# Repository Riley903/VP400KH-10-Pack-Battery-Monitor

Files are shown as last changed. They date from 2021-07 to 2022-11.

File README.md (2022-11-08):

# Battery Back-up System

This project is the entriety of the NiCd battery back-up system used in my parents' house for emergency power in the event of a power failure.

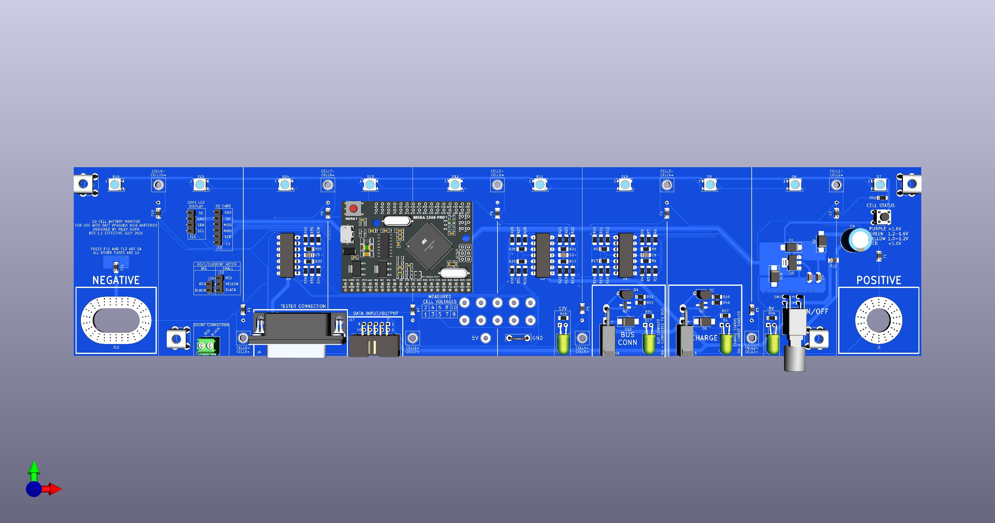
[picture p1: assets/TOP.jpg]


## Original Goal

The original goal of this project was to provide power to a water pump in the event of a power failure to provide water pressure to the house.

Recycling old heavy NiCd aircraft batteries in packs of 10 cells to provide 12V would be the electrical storage since it was free and would not need to be portable.

Several of these packs, originally 4 was deemed sufficient, would be used to power a 12V water pump from the recreational boating industry which provided the necessary 50psi at a reasonable flow rate. 

In addition to this battery storage solution, we planned to designa and build a small test unit that could calculate each cell's capacity such that we could grade them and organize them in packs of similar cells. Having 100s of cells, this is a must.

## Changes to the Original Goal

We were surprised by how effective the system was working as is with 4 packs and the pump, thus we decided to introduce 4 more packs and run an inverter to the house's main panel where it could be distributed through breakers to specific areas of the house. This would be useful for powering the lights and small appliances such as LED TVs, phone chargers, computers, and possibly the fridges and freezers.

## Some Future Plans

- Adding the 4 additional packs is still in the works.
- Water level metering to the storage tank outside.
- Silent charger for the packs.
- Upgrade the packs to the ESP32 dev board as the main controller.
- Once the ESP32's are installed, could implement a locally hosted website to view the packs and cells.
- Battery pack controllable disconnects and connects. (Look into high power transistors/thyristors capable of switching 100s of Amperes).

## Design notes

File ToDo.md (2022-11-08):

# To Do List

- Change "Charging Circuit" into a schematic of the entire system with room for additions to the project.
- Rename repository to "Battery Back-up System" since we are adding (to name a few):
    - Other cell sizes.
    - The analyzer.
    - 3D printed parts.

Check todoist for more.

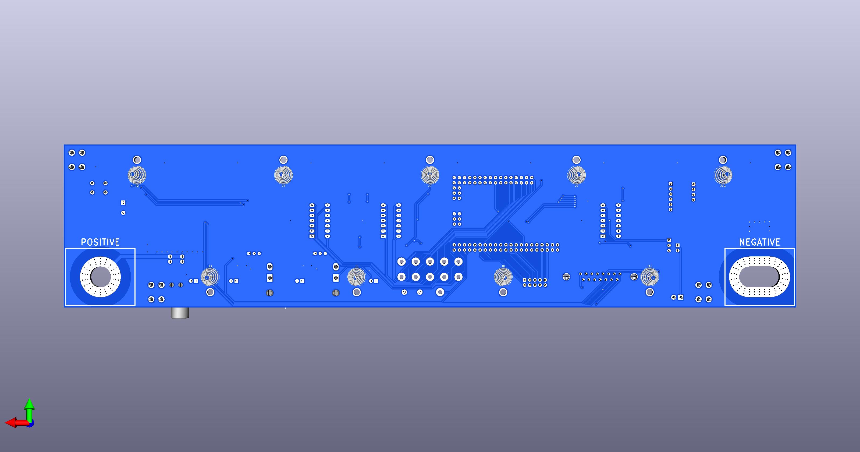
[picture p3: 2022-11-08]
NiCd Battery Shield - VP400KH/NiCd Battery Shield - VP400KH-REV 1.1/BOTTOM.jpg

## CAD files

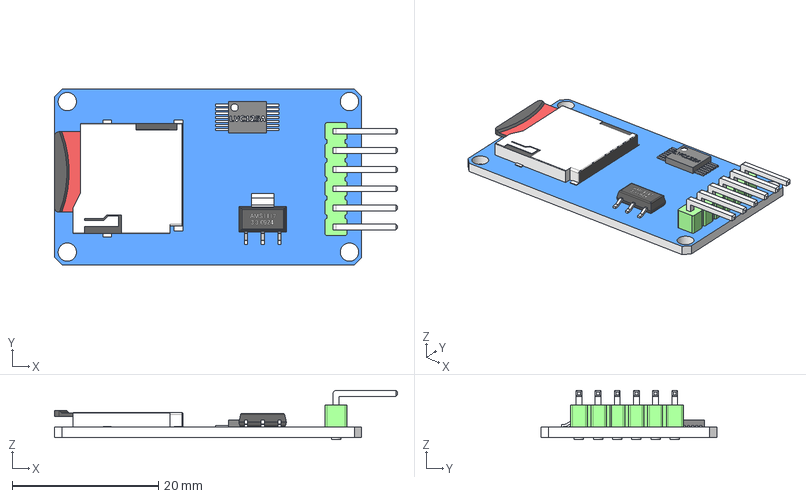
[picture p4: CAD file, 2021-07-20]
NiCd Battery Shield - VP400KH/NiCd Battery Shield - VP400KH-REV 1.1/3D Models/MicroSD Reader Assembly.stp
46.9 x 24.0 x 6.70 mm
sdreader
AMS1117
card sd

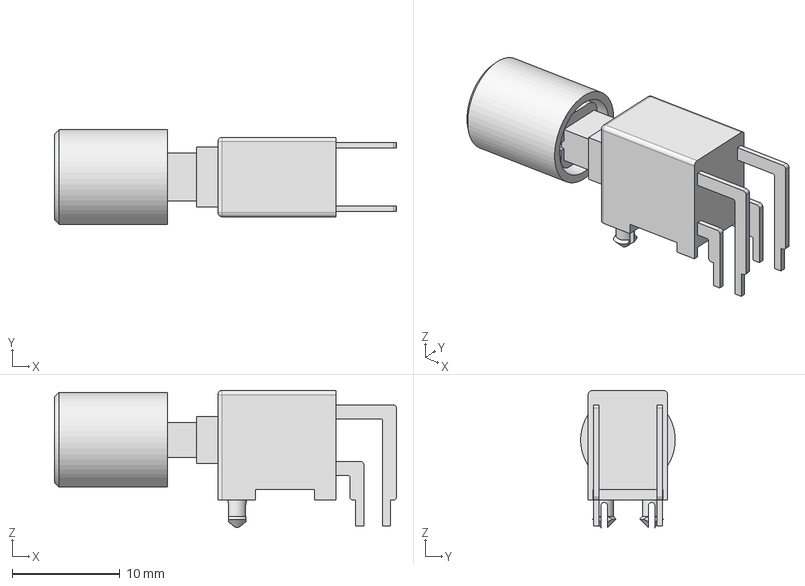
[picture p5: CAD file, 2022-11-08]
NiCd Battery Shield - VP400KH/Charging Dummy Board/3D Models/PB400xxQR1BLK.stp
31.8 x 8.79 x 12.8 mm

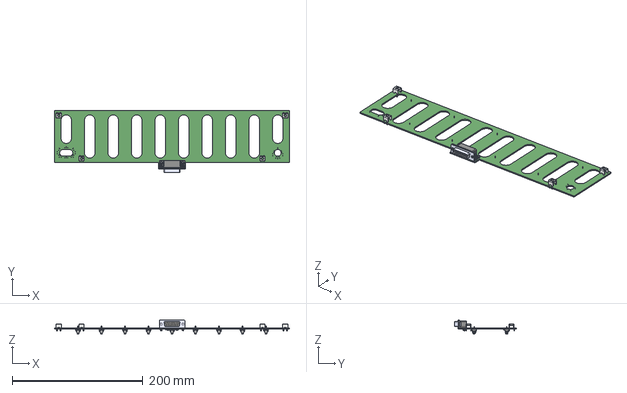
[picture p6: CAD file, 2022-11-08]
NiCd Battery Shield - VP400KH/Charging Dummy Board/NiCd Battery Shield - VP400KH.step
360.0 x 95.2 x 21.5 mm

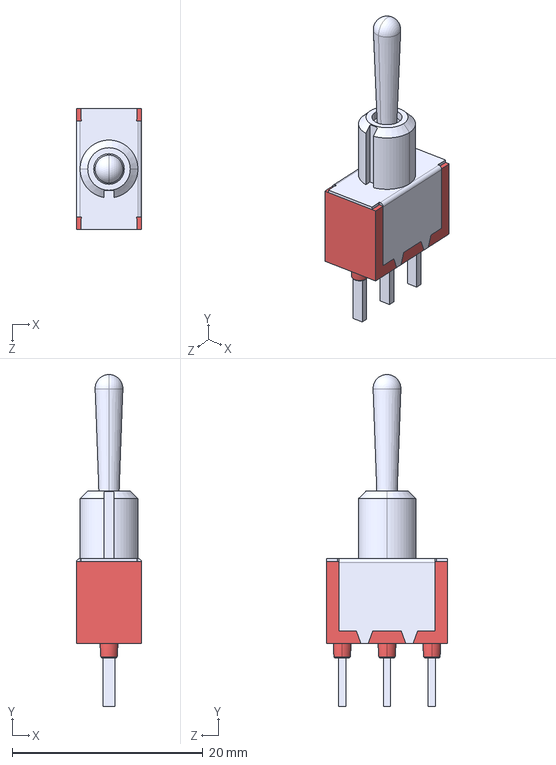
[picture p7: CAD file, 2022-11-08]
NiCd Battery Shield - VP400KH/NiCd Battery Shield - VP400KH-REV 1.1/3D Models/100SP1T1B4M2QE--3DModel-STEP-56544.STEP
6.86 x 34.8 x 12.7 mm

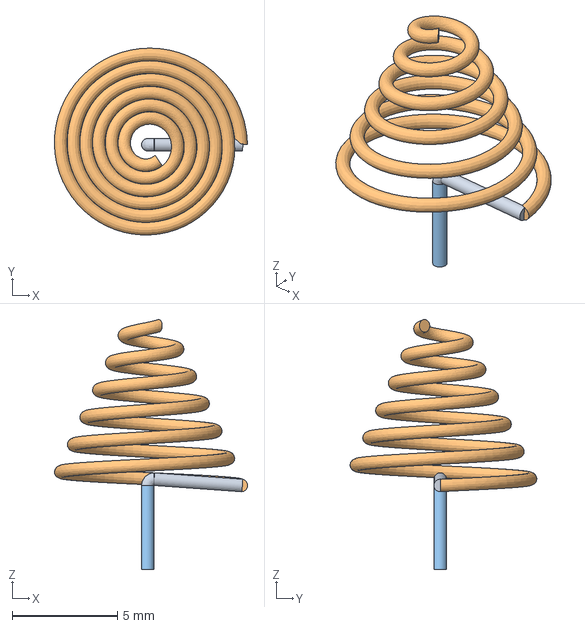
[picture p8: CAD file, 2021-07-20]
NiCd Battery Shield - VP400KH/Spring Stand-Off/3D Models/Keystone 240.step
9.20 x 8.89 x 11.9 mm

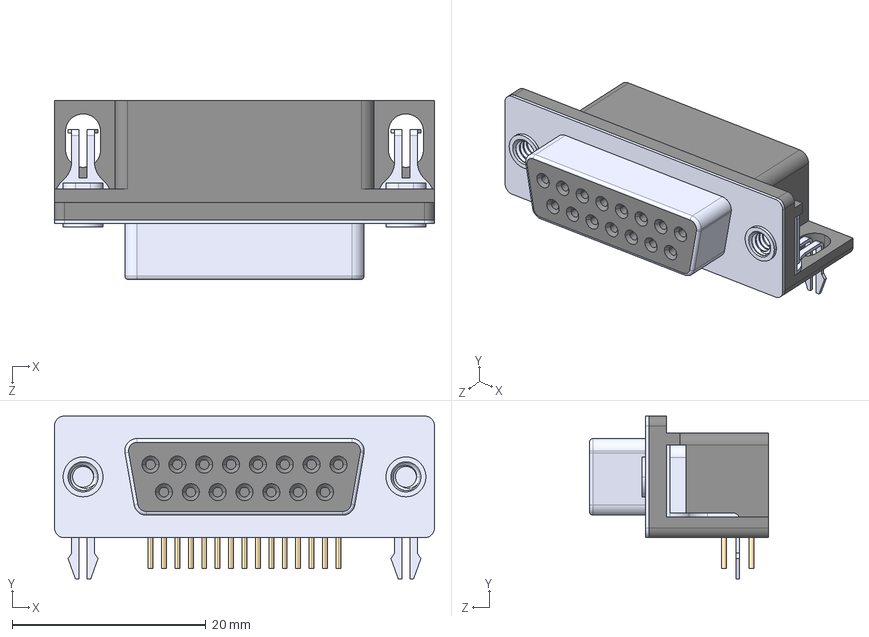
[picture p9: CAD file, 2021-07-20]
NiCd Battery Tester Rev 3/3D Models/DA15-SL-25.step
39.2 x 16.8 x 18.5 mm

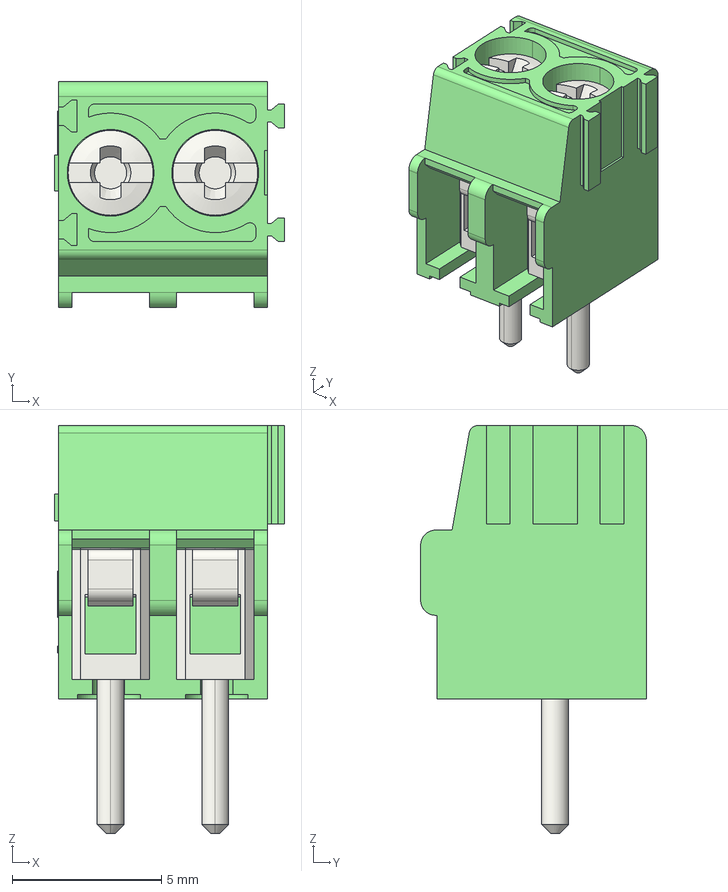
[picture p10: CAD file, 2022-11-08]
NiCd Battery Shield - VP400KH/Charging Dummy Board/3D Models/pxc_1984617_02_PT-1-5-2-3-5-H_3D.stp
7.70 x 7.55 x 13.6 mm
LP_PT_1_5_klh_3_5_horizontal.1 x 2
AC_PT_1_5_PVH_H0_Schraube x 2
AT_PT_1_5_3_50_H

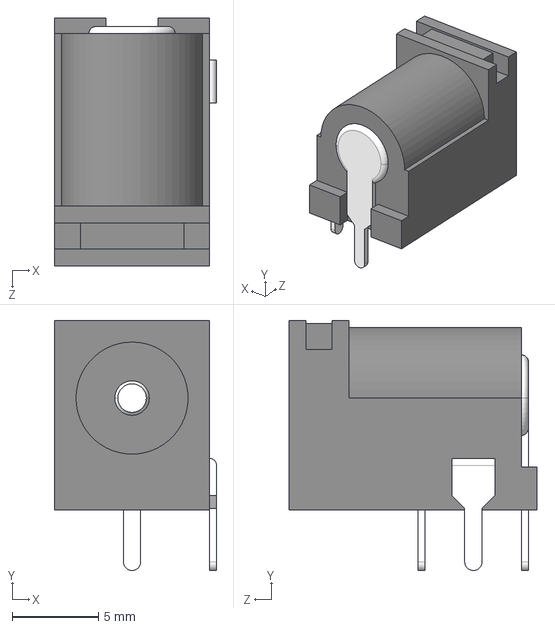
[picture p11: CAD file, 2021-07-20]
NiCd Battery Tester Rev 3/3D Models/PJ-102AH--3DModel-STEP-56544.STEP
9.40 x 14.5 x 14.4 mm

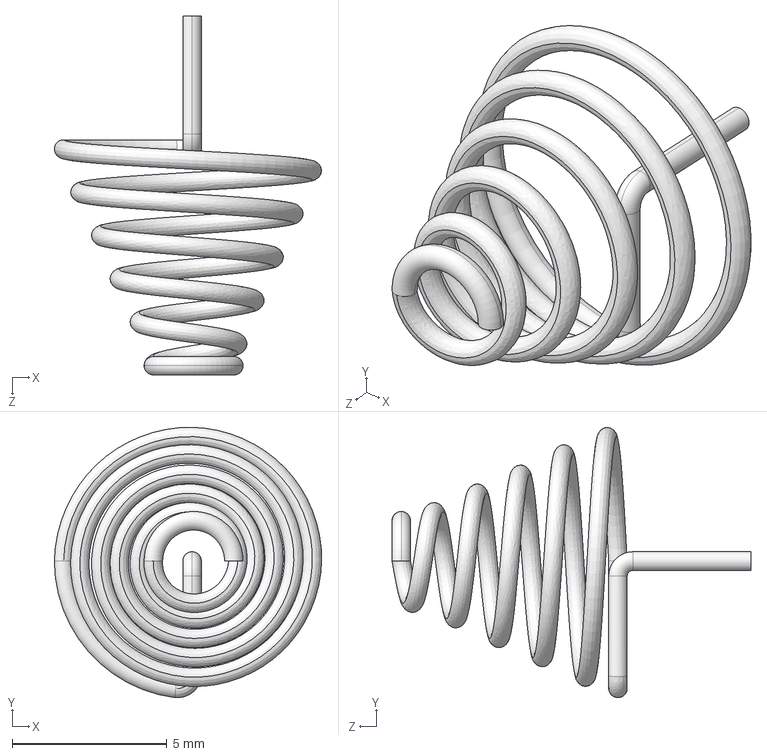
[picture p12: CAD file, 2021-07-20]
NiCd Battery Shield - VP400KH/Charging Dummy Board/3D Models/keystone-PN240.STEP
8.64 x 8.74 x 11.6 mm

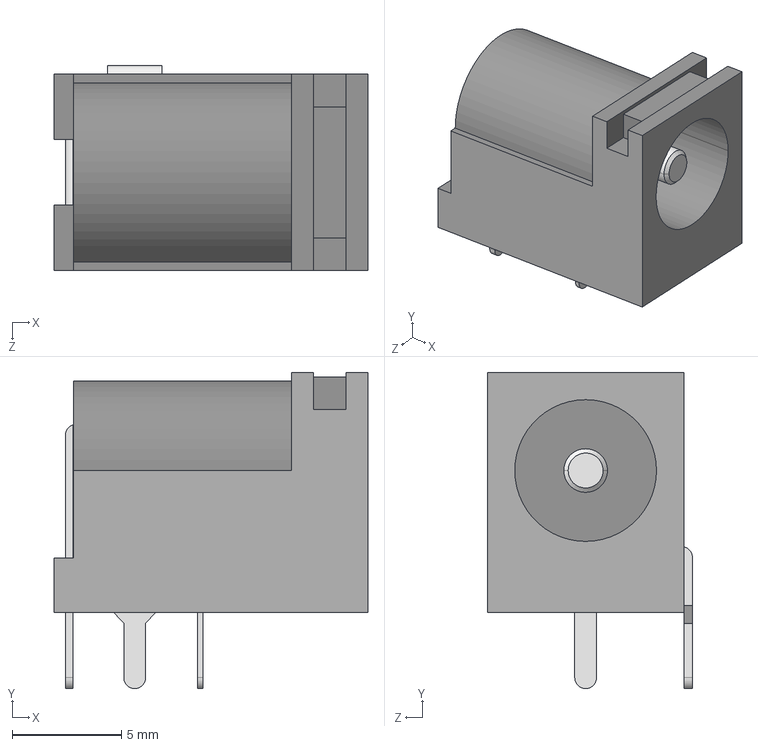
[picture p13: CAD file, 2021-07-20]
NiCd Battery Shield - VP400KH/NiCd Battery Shield - VP400KH-REV 1.1/3D Models/CUI_DEVICES_PJ-102AH.step
14.4 x 14.5 x 9.40 mm

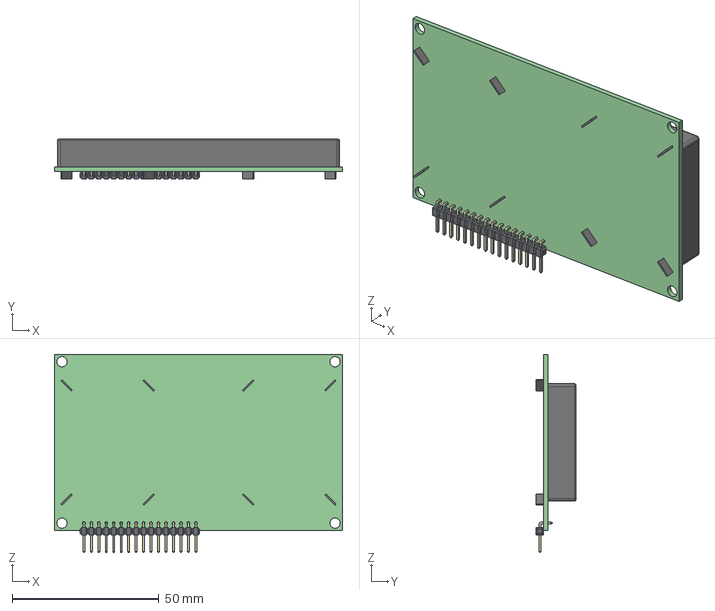
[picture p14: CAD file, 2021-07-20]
NiCd Battery Tester Rev 3/3D Models/QP5522 Jaycar 20x4 LCD Module Vertical v3 v1.step
98.0 x 13.5 x 67.5 mm

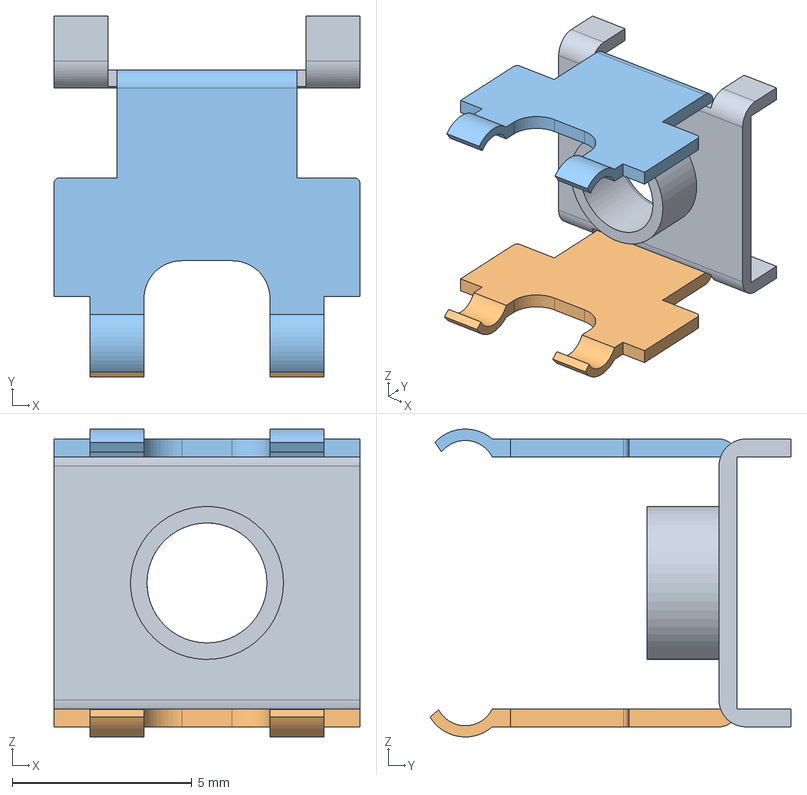
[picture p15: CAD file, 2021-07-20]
NiCd Battery Shield - VP400KH/Charging Dummy Board/3D Models/OT-047-M4 - PCB Terminal, Brass, 1.8 mm, Tin.step
8.50 x 10.0 x 8.55 mm

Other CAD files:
NiCd Battery Shield - VP400KH/Charging Dummy Board/3D Models/95947A018_ALUM FEM THRDED HEX STANDOFF.STEP
NiCd Battery Shield - VP400KH/Charging Dummy Board/3D Models/CUI_DEVICES_TB005-762-02BE.step
NiCd Battery Shield - VP400KH/Charging Dummy Board/3D Models/Molex-2Pos-RA.stp
NiCd Battery Shield - VP400KH/Charging Dummy Board/3D Models/keystone-PN7795.STEP
NiCd Battery Shield - VP400KH/NiCd Battery Shield - VP400KH-REV 1.0/3D Models/95947A018_ALUM FEM THRDED HEX STANDOFF.STEP
NiCd Battery Shield - VP400KH/NiCd Battery Shield - VP400KH-REV 1.0/3D Models/CUI_DEVICES_TB005-762-02BE.step
NiCd Battery Shield - VP400KH/NiCd Battery Shield - VP400KH-REV 1.0/3D Models/Molex-2Pos-RA.stp
NiCd Battery Shield - VP400KH/NiCd Battery Shield - VP400KH-REV 1.0/3D Models/keystone-PN7795.STEP
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

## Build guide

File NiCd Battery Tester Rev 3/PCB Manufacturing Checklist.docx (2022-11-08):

# Things to consider before designing the PCB layout:

- Set up the Design Rules to correspond with the intended attributes of the board. This may include:
  - Design rules comply with the manufacturer’s capabilities.
  - Trace width for each circuit. Compensate for copper thickness.
  - Electrical spacing suitable for voltage levels?
  - Altitude considerations?
  - High Frequency circuits?
- Refer to the documentation of each component used and review the suggested layout and recommended complementary components.
- Will this board be assembled by the manufacturer? See “Design for Assembly”
- Is it possible to mount all SMD components on a single side?

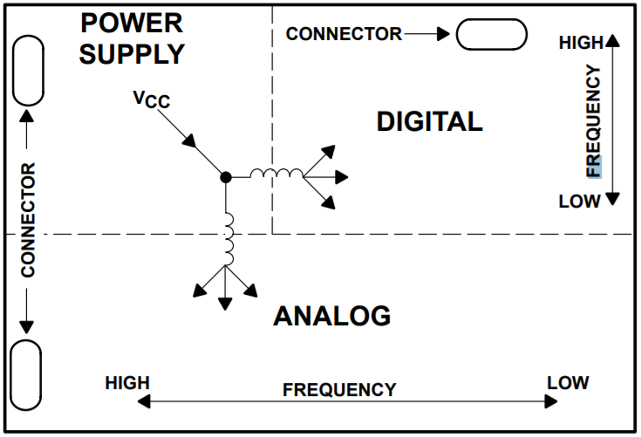
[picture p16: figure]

# Things to accompany the fabrication files:

- Power demand calculations.
- Component BOM and datasheets if applicable.
- List of desired manufacturers and what PCB specifications were considered in the design? Track spacing, copper weight, surface finish etc.

Board: | NiCd 10 Cell Battery Tester Rev 3
Reviewed By: | Date:
Riley | April 23 2021

# 1. Schematic Review

Item | Description | Yes/No | Comments
1.1 | Do all the chips on the board have bypass and/or filter capacitors, and are they placed as close as possible to the power pins? | YES
1.2 | Are unused input pins properly pulled or tied to their desired logic levels and not left floating? | N/A
1.3 | Have the single source components in the design been identified? Where possible, have components been selected using the most common industry standard packages allowing for second source alternatives? | OK
1.4 | Has the bill of material been reviewed to minimize the number of unique components in the design? | OK
1.5 | Have the voltage ratings for capacitors and other passives been verified? At least 1.5x to 2x the operating voltage. | YES
1.6 | Has a power budget been completed for this board? Are the LDO regulators able to supply the load current without excessive heat loss? | YES
1.7 | Do connectors exposed to the outside world have adequate ESD/TVS protection? | NO
1.8 | Do all active components have Power and Ground connected? Are they connected to the correct power and grounds? | YES
1.9 | Have timing crystals been connected with the appropriate resonance capacitors? Have oscillators’ internal capacitors been grounded appropriately? | N/A

# 2. Part Design

Item | Description | Yes/No | Comments
2.1 | Have the pin assignments in the schematic been verified against the part datasheets? | YES
2.2 | Have the mechanical dimensions been verified for all the component footprints? | YES
2.3 | Are any component datasheets showing the pin assignments from the bottom perspective? If so, is this accounted for? | NO
2.4 | Are the drill sizes for all the through hole components large enough, or too large, for the pin diameters? | YES
2.5 | Has the pin order been verified on all the connectors? Also take into consideration if the mating cable reverses the pin order. | YES
2.6 | Are the connectors adequately keyed to prevent backwards cable insertion? | N/A
2.7 | Have passive values been consolidated to minimize unique parts? (e.g. do you really need a 10k and a 12k resistor in the design?) | OK
2.8 | Have tuned values (e.g. amplifier or regulator feedback circuits) been tweaked to E12 or E24 series values where feasible? | OK

# 3. PCB Mechanical

Item | Description | Yes/No | Comments
3.1 | Have the dimensions of the mating cables been considered when spacing the PCB connectors? Has finger access to cables been considered in the connector spacing? | OK
3.2 | If the circuit board is going into an enclosure, are the connectors positioned to be flush with the enclosure outer surfaces? | N/A
3.3 | If the circuit board is going into a tight fitting enclosure, have component heights and other mechanical keepouts been accounted for? | N/A
3.4 | Are the mounting holes in logical and the correct locations, and are their diameters correct for the intended mounting screws with plating thickness accounted for? Are the mounting hole diameters also correct (not too large) when considering the outer diameter of the enclosure standoffs? | YES
3.5 | Do components and traces have adequate spacing away from mounting holes to account for the screw head diameter or potential damage due to a drill bit slipping during assembly? | YES
3.6
3.7

# 4. Silkscreen

Item | Description | Yes/No | Comments
4.1 | Does the silk screen include company name, project number, part number, and PCB revision? | YES
4.2 | Are all the silk screen labels oriented uniformly or in only two orientations? | YES
4.3 | Are all the silk screen labels clear of solder pads and via drills? | YES
4.4 | Do all the passive components with placement orientation (electrolytic capacitors, diodes, LEDs, etc) have adequate silkscreen markings to indicate the install polarity? | YES
4.5 | Is pin 1 marked on all ICs where incorrect rotation is possible? | YES
4.6 | Do connectors have pin numbers or markings that show the pin or connector usage and will remain legible when the connector is installed? | YES
4.7 | Any additional information required on the silkscreen to aid the user? Legend, replacement parts, etc. | OK
4.8 | Are the test points or critical circuits labelled? | YES
4.9 | Do component labels far from their components have a line, arrow or logical arrangement that indicates which component they refer to? | OK
4.10 | Are fuses’ rating and type listed on the board? | YES
4.11 | In the case of insufficient space to label all components, have the most important components been given priority? Generally: 1. Connectors 2. Fuses (including rating) 3. ICs 4. Crystals 5. Test points 6. Tuned passives (i.e. amplifier or regulator feedback circuits) 7. Termination resistors/capacitors 8. Bypass Capacitors 9. Pullup/down resistors | OK

# 5. Copper Design

Item | Description | Yes/No | Comments
5.1 | Does the PCB layout software confirm that all nets are 100% routed? | YES
5.2 | Have the PCB design rules been configured to comply with the manufacturer’s minimum spacings and feature sizes? | YES
5.3 | Does the PCB layout software Design Rule Check pass? | YES
5.4 | Have all the pads been verified as having good pad exits; no traces exiting at unusual acute angles? | YES
5.5 | Are all the high current traces accounted for? Do they use sufficient copper width to handle the current? | YES
5.6 | Do all components through holes and SMD solder pads have thermal isolation (wagon wheels) from ground planes and copper pours? | YES
5.7 | Do high power components have adequate heat sinking using PCB copper heatsink or mechanical heat sink? | YES
5.9 | Does the ground fill meet up with all of the desired grounded nets? No isolated islands of copper? | OK
5.10 | High power or noisy traces do not run near sensitive components or traces for such components? | OK
5.11 | Multiple vias for high current or low impedance circuits? Impedance of critical traces has been calculated and is acceptable. | YES
5.12 | Are switched mode power supplies laid out per the manufacturer datasheet recommendations? Is loop area minimized for resonant current loops? | N/A

# 6. Design for Assembly

Item | Description | Yes/No | Comments
6.1 | Does the PCB have at least 3 fiducials? | YES
6.2 | Are surface mount components used wherever possible instead of through holes? This improves assembly automation, quality, and manufacturing cost. | YES
6.3 | For all through hole components, are the bottom side copper rings nice and wide to allow for easy wave/hand soldering? Pins that are tight pitch can use ovals or rectangular annular rings. | YES
6.4 | Are bottom side SMT components appropriately spaced away from through hole pins? | N/A
6.5 | Do all traces and components have sufficient clearance away from the edge of the board? | YES
6.6 | Panel design required? | NO
6.7

# 7. Design for Test

Item | Description | Yes/No | Comments
7.1 | Does the circuit board have sufficient test points and locations for probing of critical signals and monitoring supply voltages? Are there convenient locations for attaching the probe leads? | YES
7.2 | Does the board include adequate structures or connectors for firmware load or functional test? | N/A
7.3 | If the board is intended for high volume manufacturing, does the design include bottom side solder mask openings to allow for a bed of nails in-circuit test? | N/A
7.4 | Can the board be easily debugged? Critical circuits can be measured from a single side or when installed in the intended position? | YES
7.5
7.6

# 8. High Speed Signals

Item | Description | Yes/No | Comments
8.1 | Are traces carrying high speed signals designed as transmission lines using appropriate PCB impedance? | N/A
8.2 | Do high speed signals use the correct terminations as suggested by the part manufacturer? | N/A
8.3 | Are high speed signals routed over solid unobstructed copper planes? | N/A
8.4 | Are high speed differential pairs routed using proper symmetry and length matching? | N/A
8.5 | Are traces spaced and routed to minimize crosstalk? | N/A
8.6

# 9. PCB Fabrication

Item | Description | Yes/No | Comments
9.1 | Are the fabrication files up to date?
9.2 | Are all the fabrication files in the zipped folder? Drill files, GERBERS, etc.
9.3 | Does the Design Rule Check pass without warnings or errors? | YES
9.4 | Has the list of desired manufacturers and what PCB specifications were considered in the design been reviewed and adhered to?
9.5
9.6
9.7

# 10. Notes

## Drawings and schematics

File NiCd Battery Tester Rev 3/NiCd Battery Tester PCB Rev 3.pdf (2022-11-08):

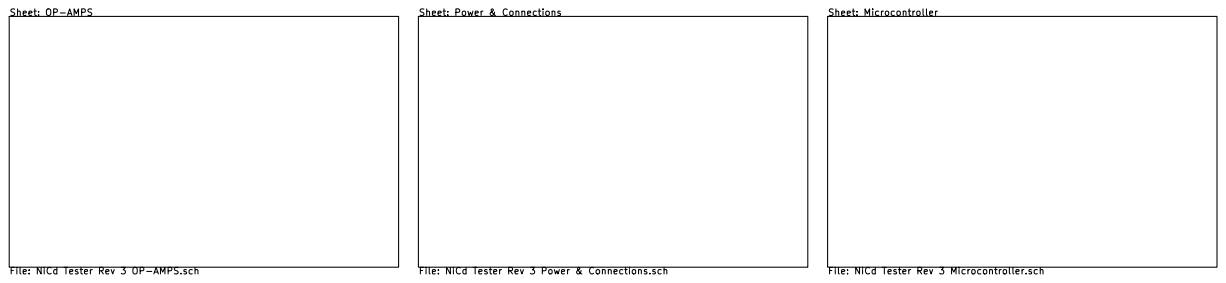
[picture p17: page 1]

File: NiCd Battery Tester PCB Rev 3.sch Sheet: /
Id: 1/4 Title: NiCd CELL TESTING SHIELD

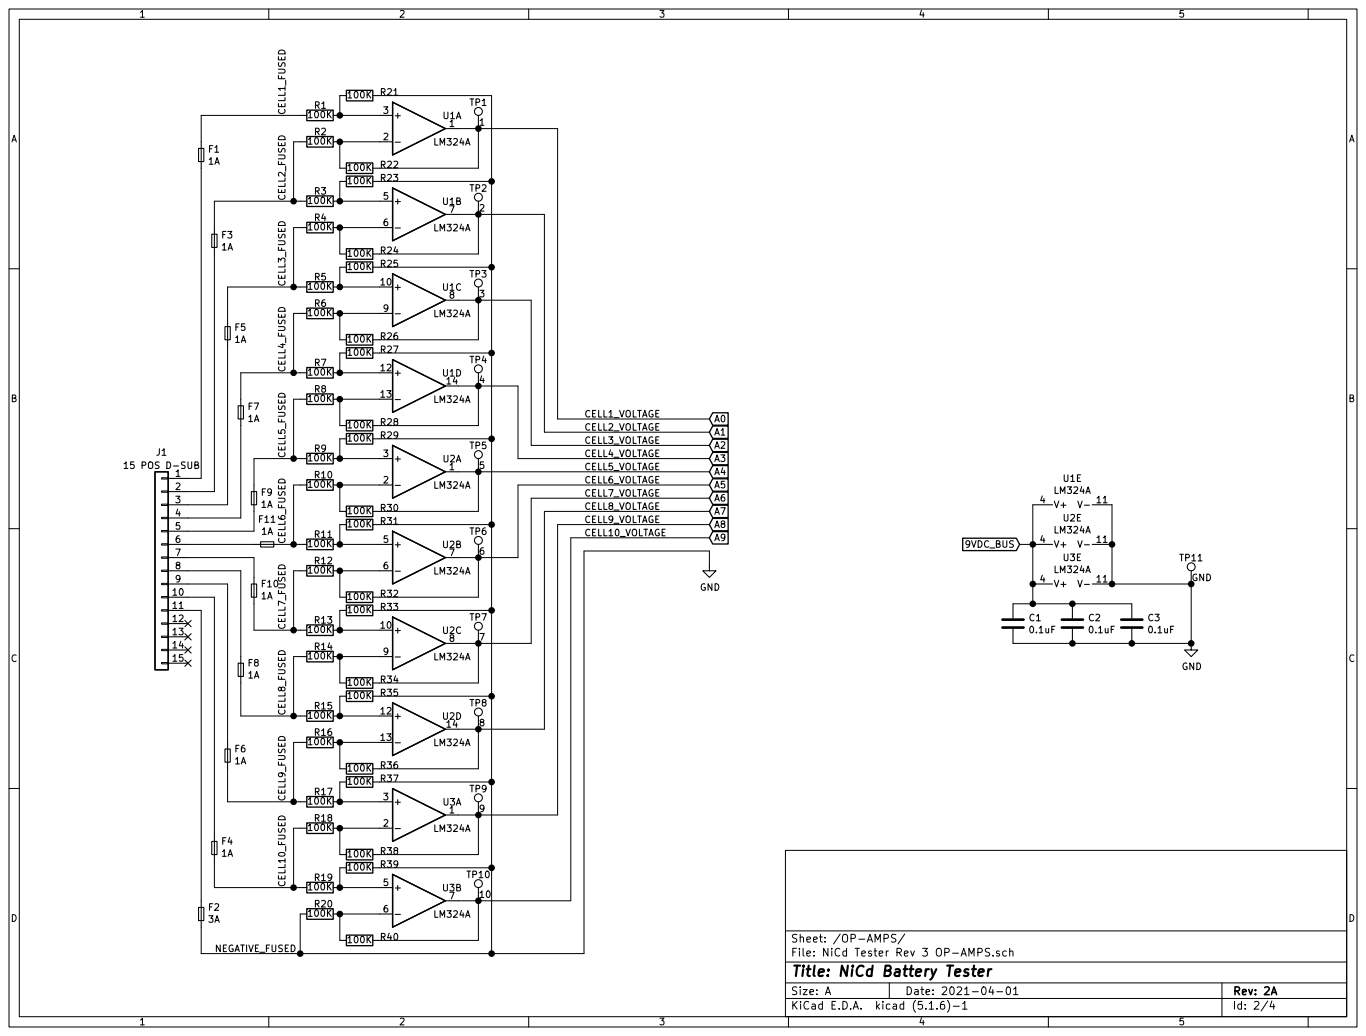
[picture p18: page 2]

Id: 2/4 Title: NiCd Battery Tester File: NiCd Tester Rev 3 OP-AMPS.sch Sheet: /OP-AMPS/ F6

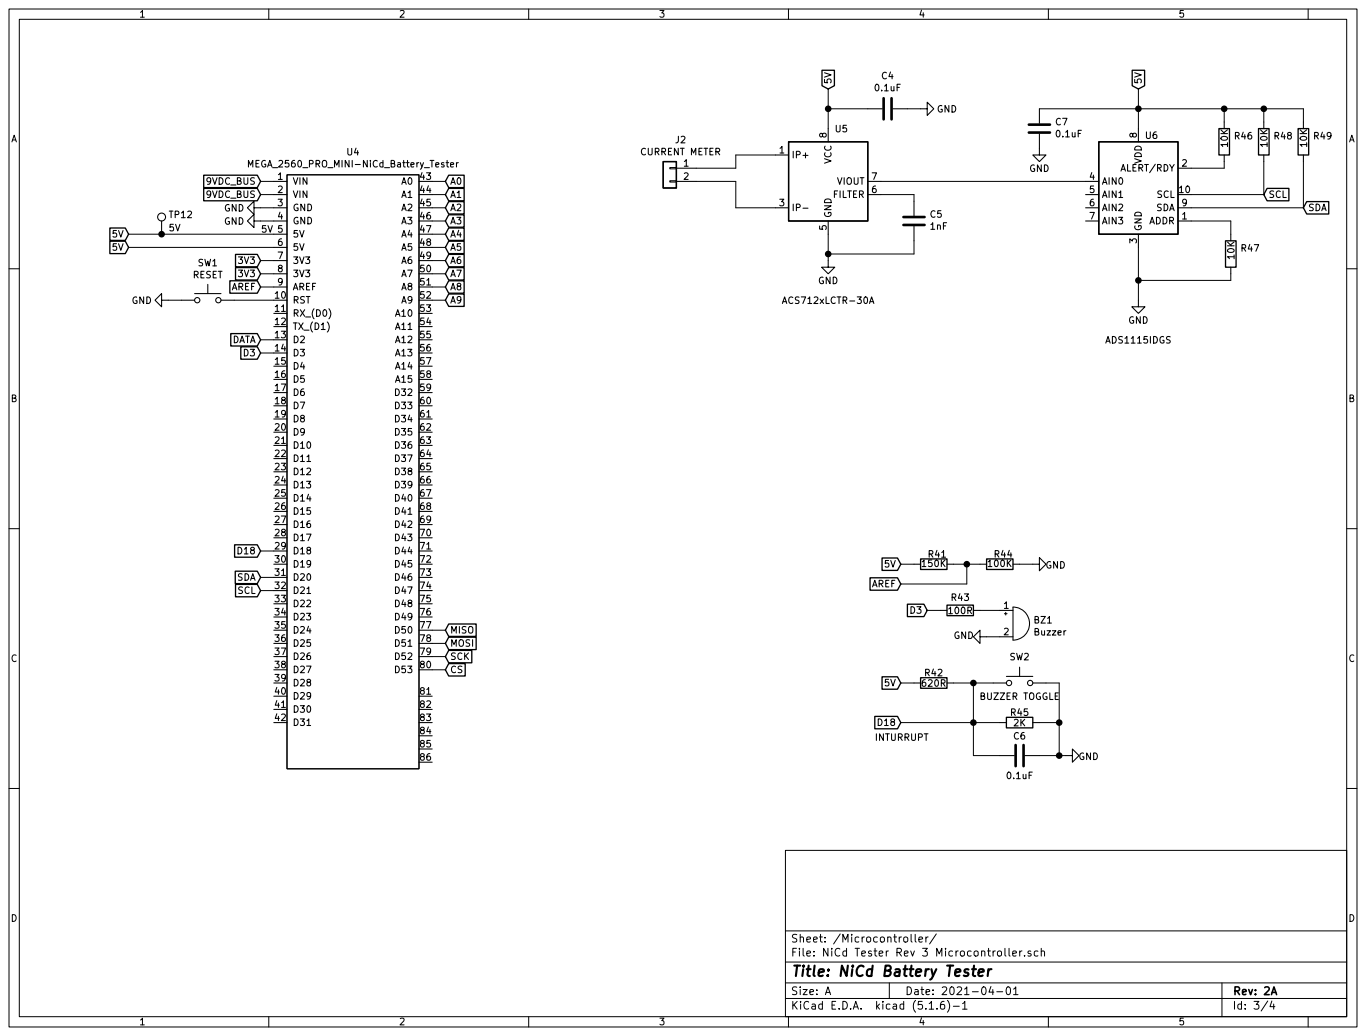
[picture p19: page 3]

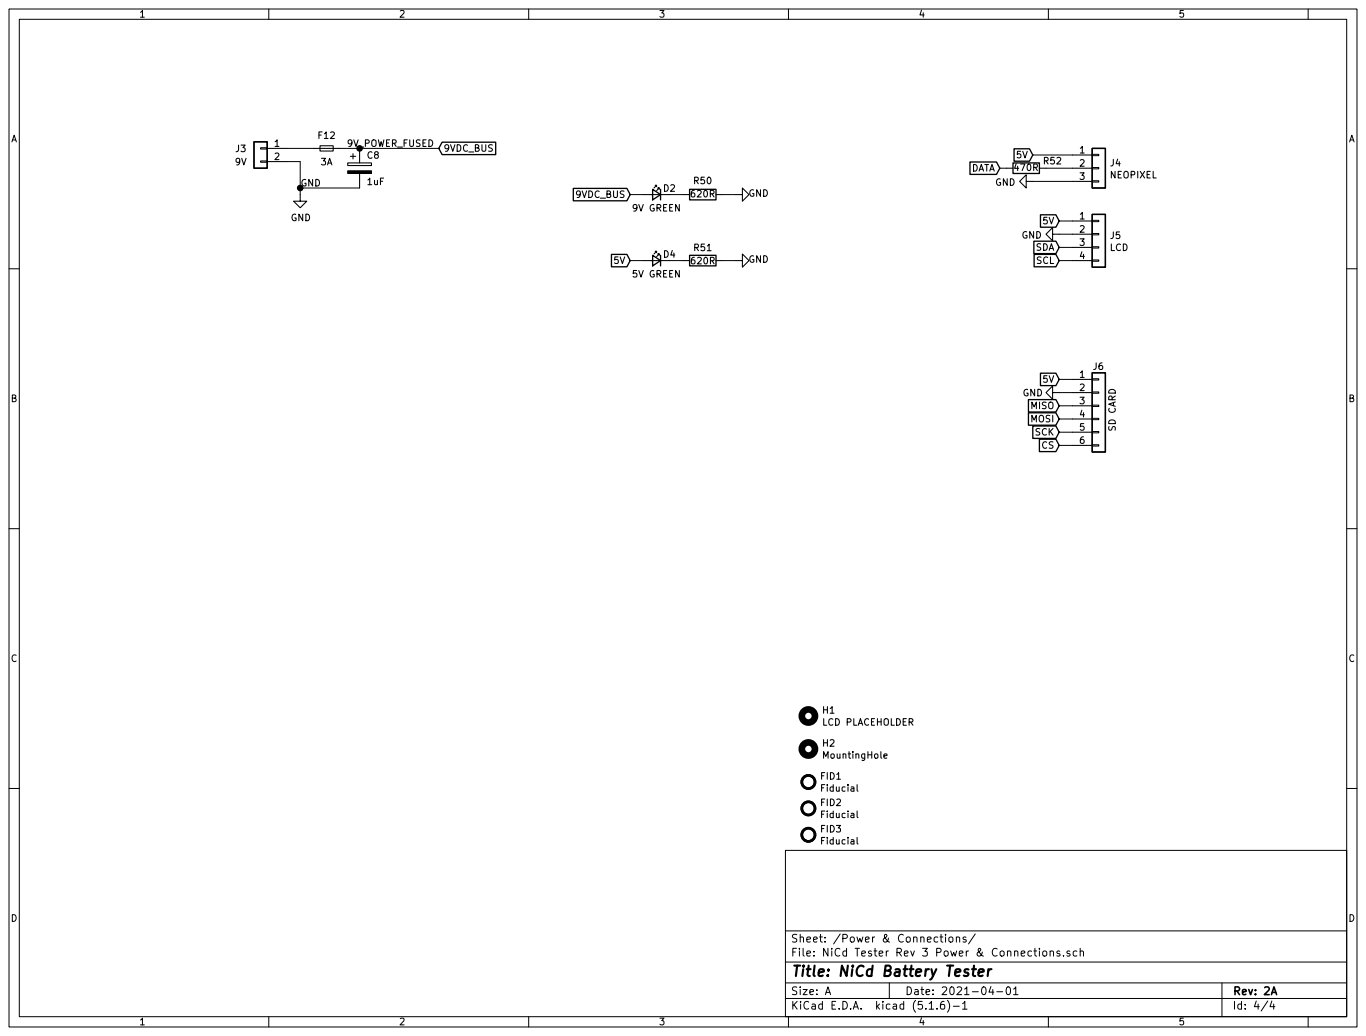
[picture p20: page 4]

Id: 4/4 Title: NiCd Battery Tester File: NiCd Tester Rev 3 Power & Connections.sch Sheet: /Power & Connections/

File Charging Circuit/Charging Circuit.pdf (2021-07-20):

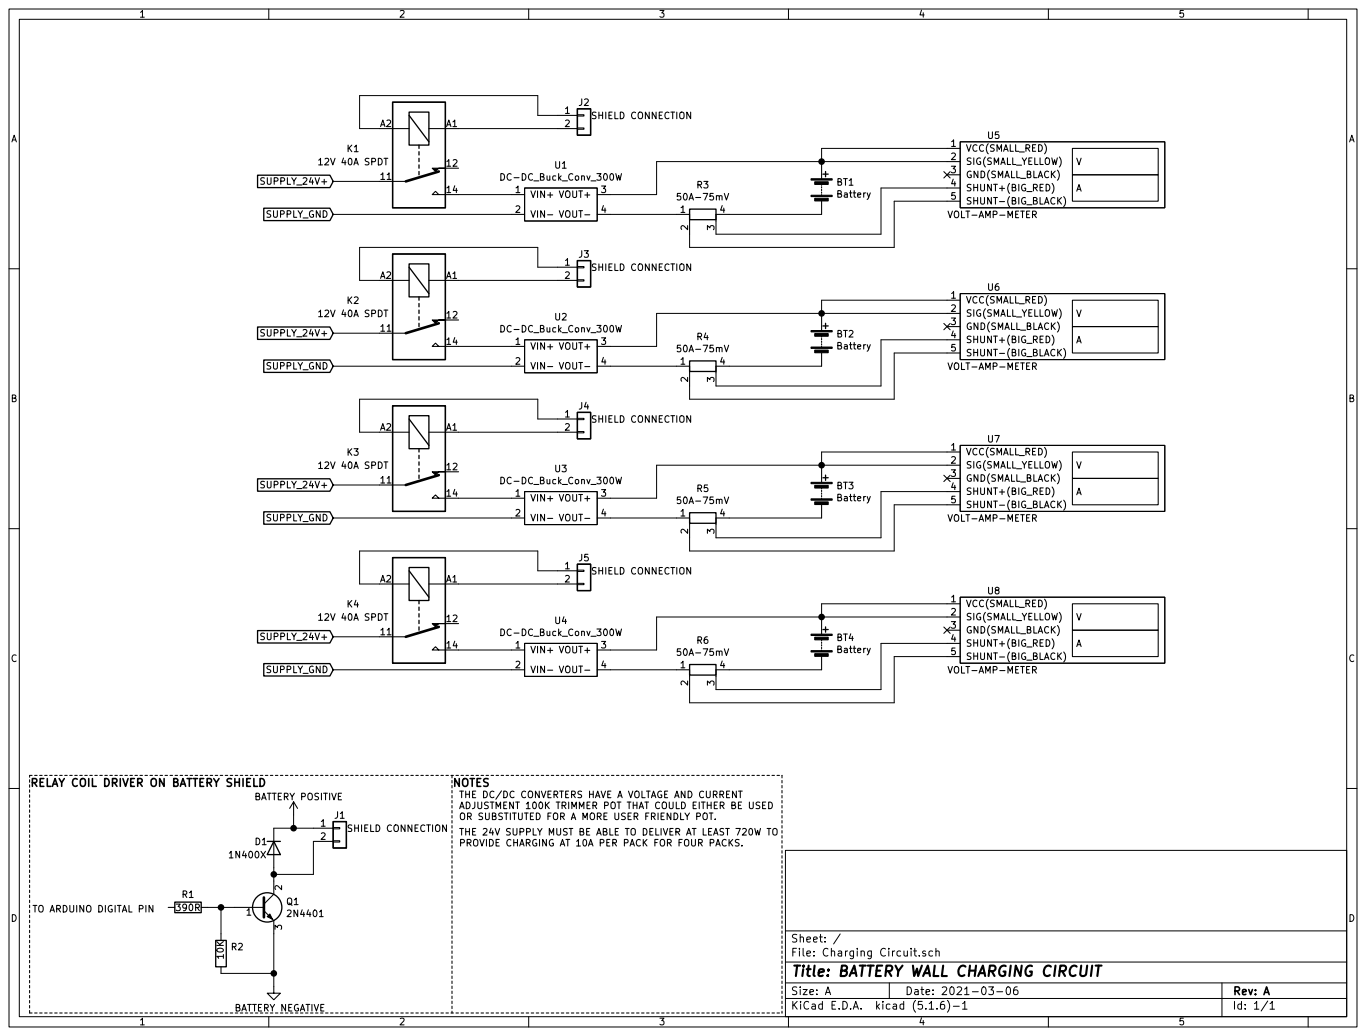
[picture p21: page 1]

SUPPLY_24V+ RELAY COIL DRIVER ON BATTERY SHIELD

THE 24V SUPPLY MUST BE ABLE TO DELIVER AT LEAST 720W TO PROVIDE CHARGING AT 10A PER PACK FOR FOUR PACKS. NOTES
THE DC/DC CONVERTERS HAVE A VOLTAGE AND CURRENT ADJUSTMENT 100K TRIMMER POT THAT COULD EITHER BE USED OR SUBSTITUTED FOR A MORE USER FRIENDLY POT.

TO ARDUINO DIGITAL PIN

File: Charging Circuit.sch Sheet: /
Id: 1/1 Title: BATTERY WALL CHARGING CIRCUIT

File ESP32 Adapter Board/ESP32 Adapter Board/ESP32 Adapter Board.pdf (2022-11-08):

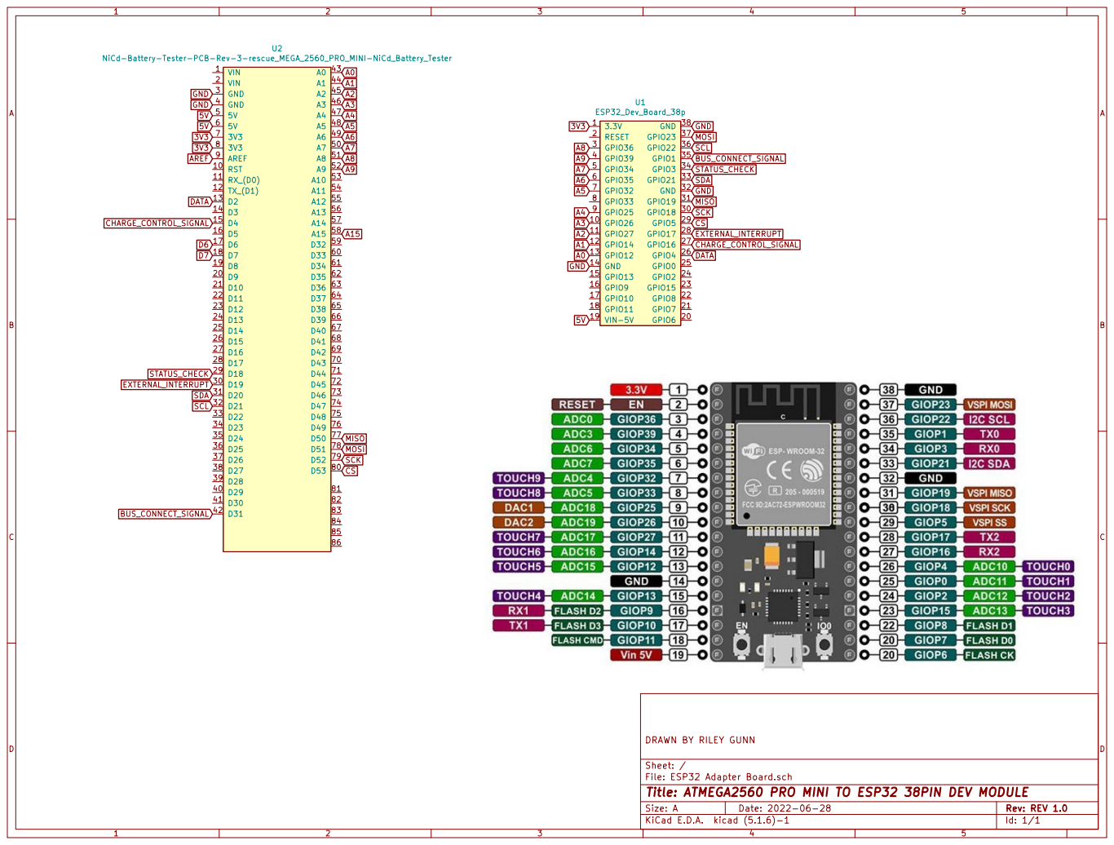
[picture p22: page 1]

File: ESP32 Adapter Board.sch Sheet: / DRAWN BY RILEY GUNN

Id: 1/1 Title: ATMEGA2560 PRO MINI TO ESP32 38PIN DEV MODULE

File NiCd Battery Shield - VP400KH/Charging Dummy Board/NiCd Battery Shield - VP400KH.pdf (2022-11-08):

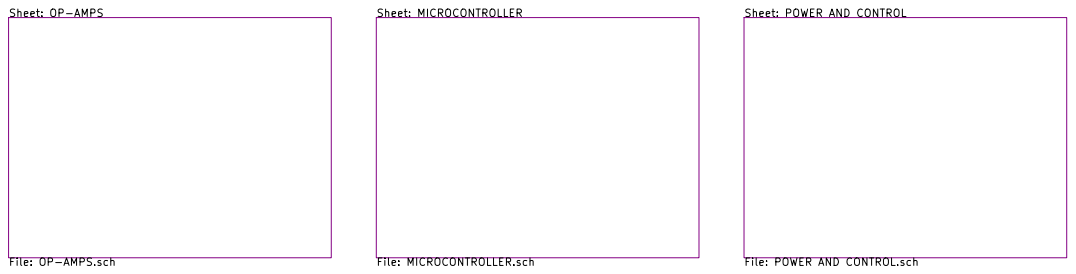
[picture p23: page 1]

File: NiCd Battery Shield - VP400KH.sch Sheet: /
Id: 1/4 Title: NiCd BATTERY MONITOR SHIELD - VP400KH

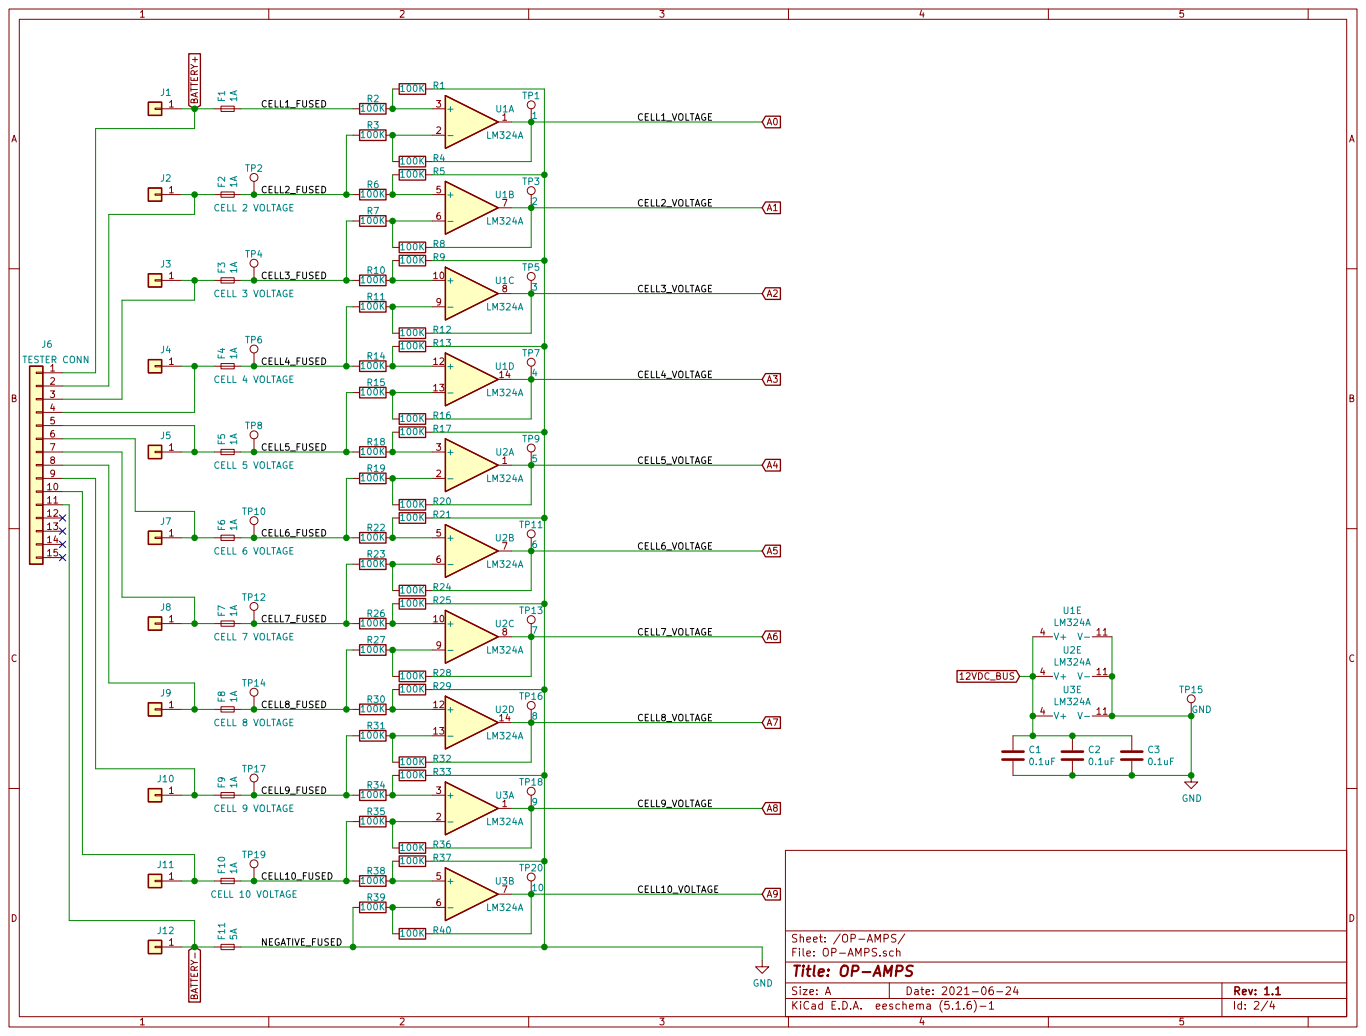
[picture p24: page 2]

Id: 2/4 Title: OP-AMPS

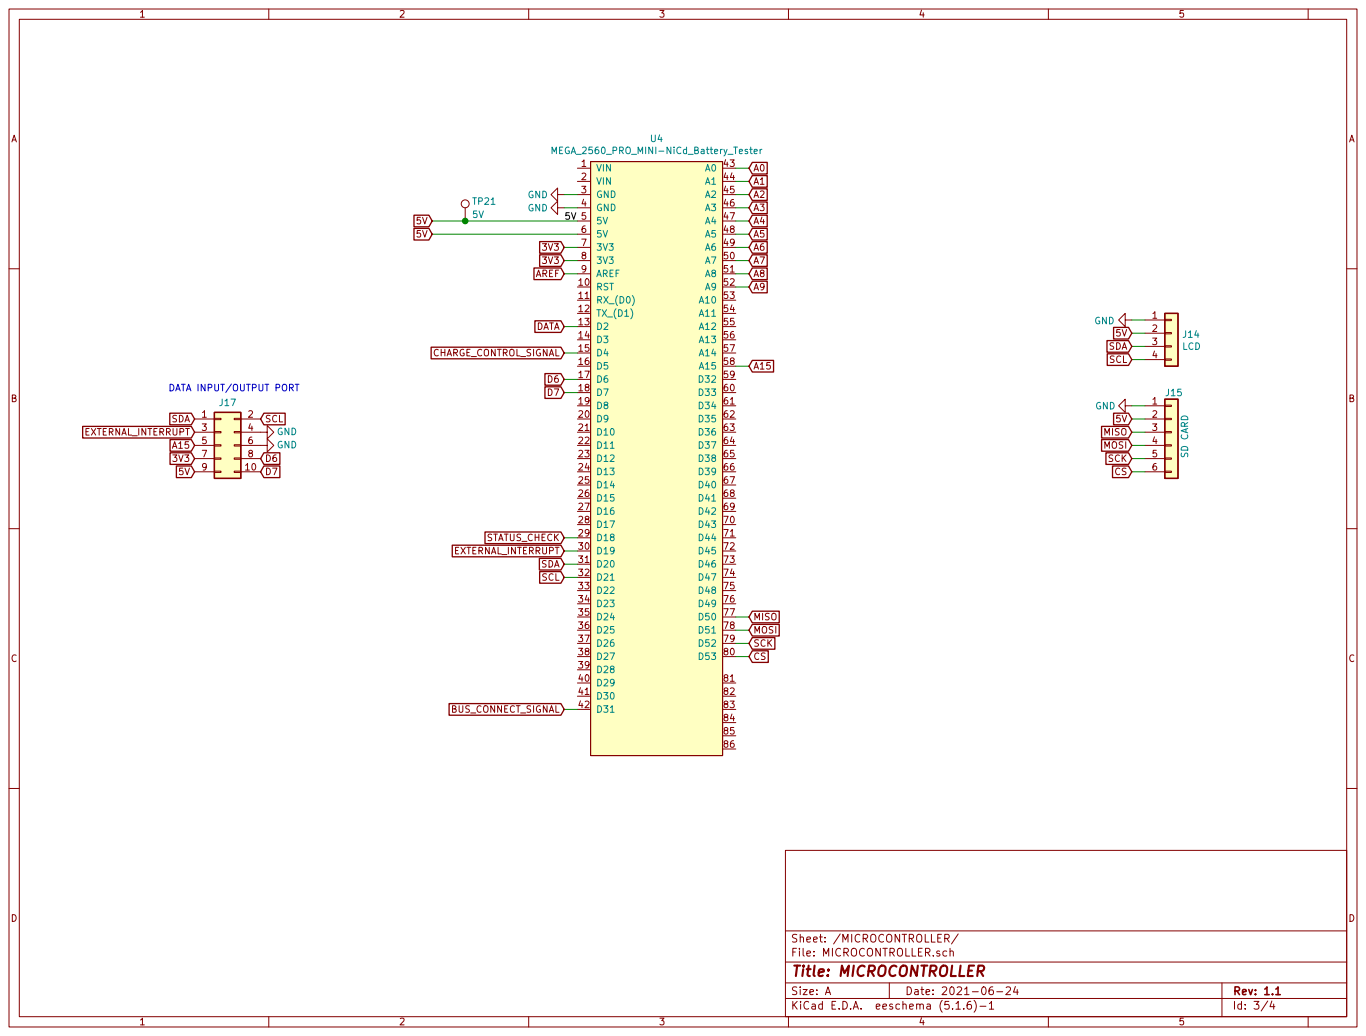
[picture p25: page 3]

5V DATA INPUT/OUTPUT PORT

File: MICROCONTROLLER.sch Sheet: /MICROCONTROLLER/
Id: 3/4 Title: MICROCONTROLLER

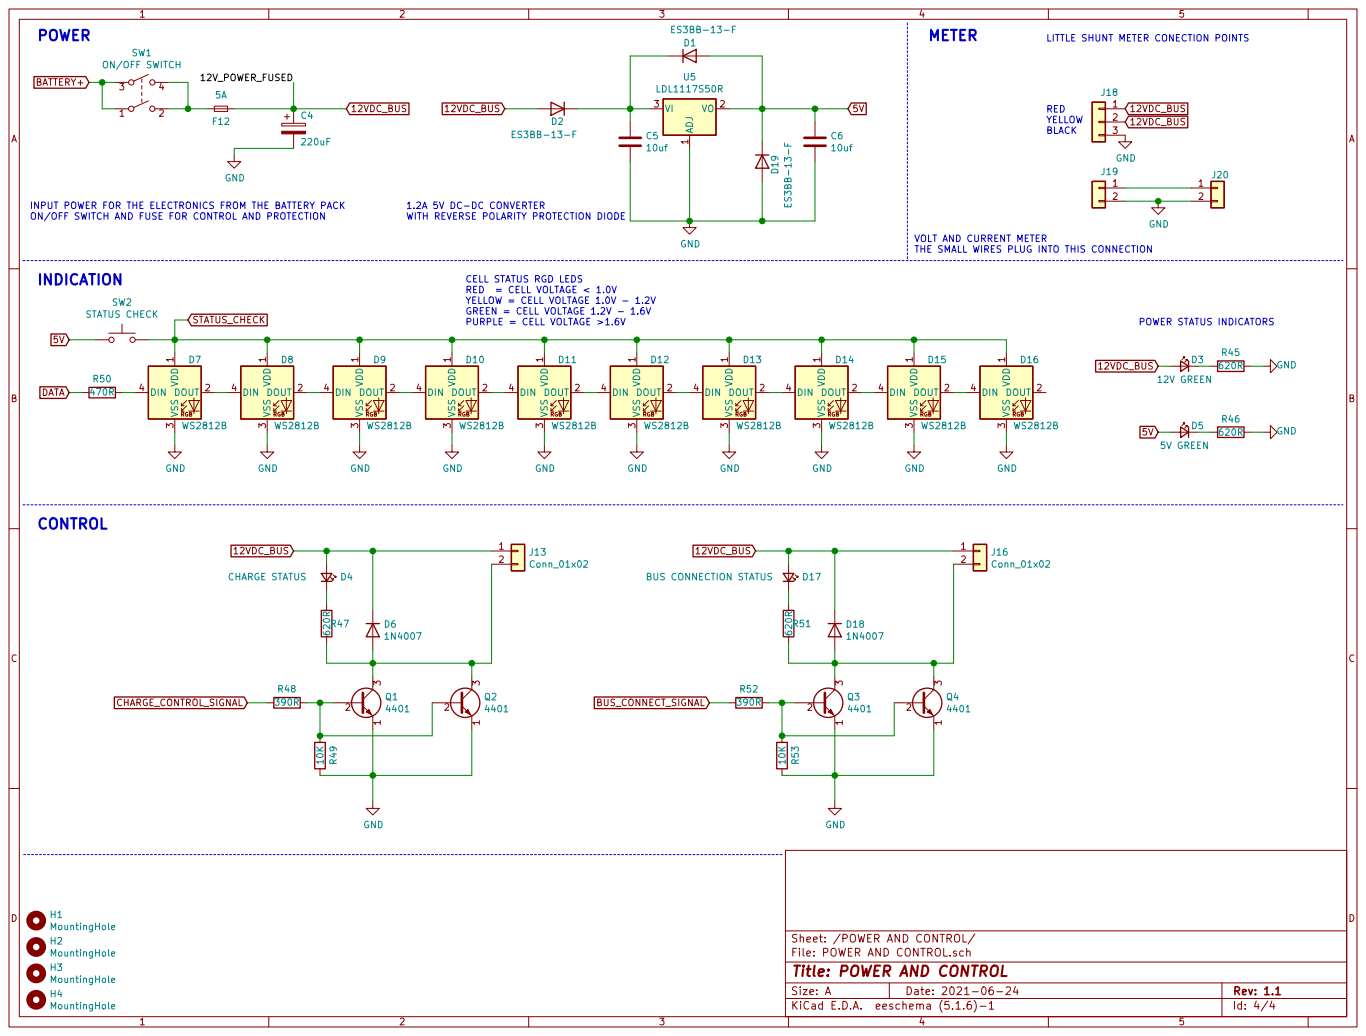
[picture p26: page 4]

INPUT POWER FOR THE ELECTRONICS FROM THE BATTERY PACK ON/OFF SWITCH AND FUSE FOR CONTROL AND PROTECTION

VOLT AND CURRENT METER
THE SMALL WIRES PLUG INTO THIS CONNECTION

YELLOW = CELL VOLTAGE 1.0V - 1.2V GREEN = CELL VOLTAGE 1.2V - 1.6V

File: POWER AND CONTROL.sch Sheet: /POWER AND CONTROL/ GND

Id: 4/4 Title: POWER AND CONTROL

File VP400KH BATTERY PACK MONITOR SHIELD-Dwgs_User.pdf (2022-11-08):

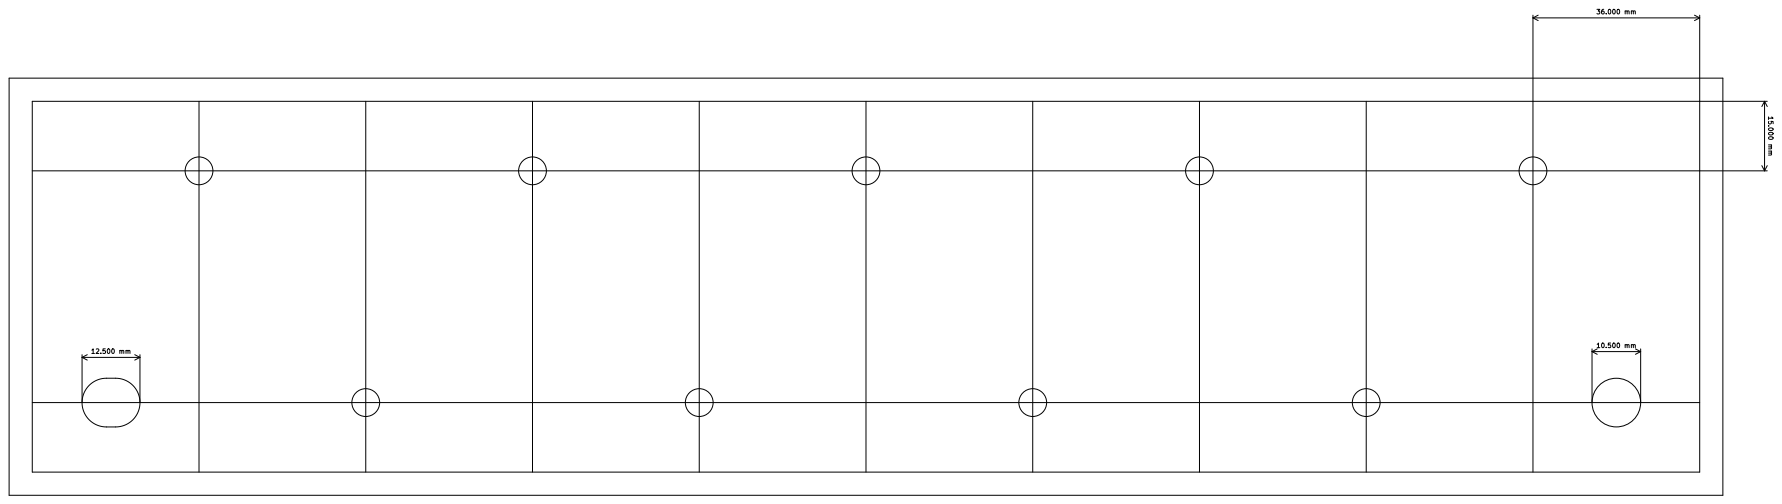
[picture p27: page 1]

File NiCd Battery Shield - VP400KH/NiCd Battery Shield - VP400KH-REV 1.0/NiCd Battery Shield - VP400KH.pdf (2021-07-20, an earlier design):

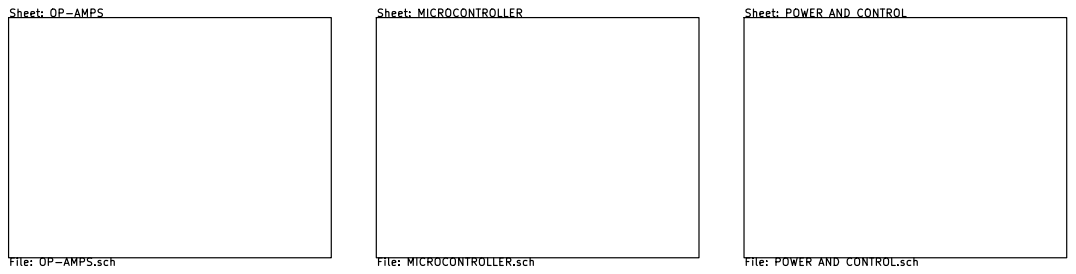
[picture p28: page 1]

File: NiCd Battery Shield - VP400KH.sch Sheet: /
Id: 1/4 Title: NiCd BATTERY MONITOR SHIELD - VP400KH


Id: 2/4 Title: OP-AMPS



Id: 4/4 Title: POWER AND CONTROL

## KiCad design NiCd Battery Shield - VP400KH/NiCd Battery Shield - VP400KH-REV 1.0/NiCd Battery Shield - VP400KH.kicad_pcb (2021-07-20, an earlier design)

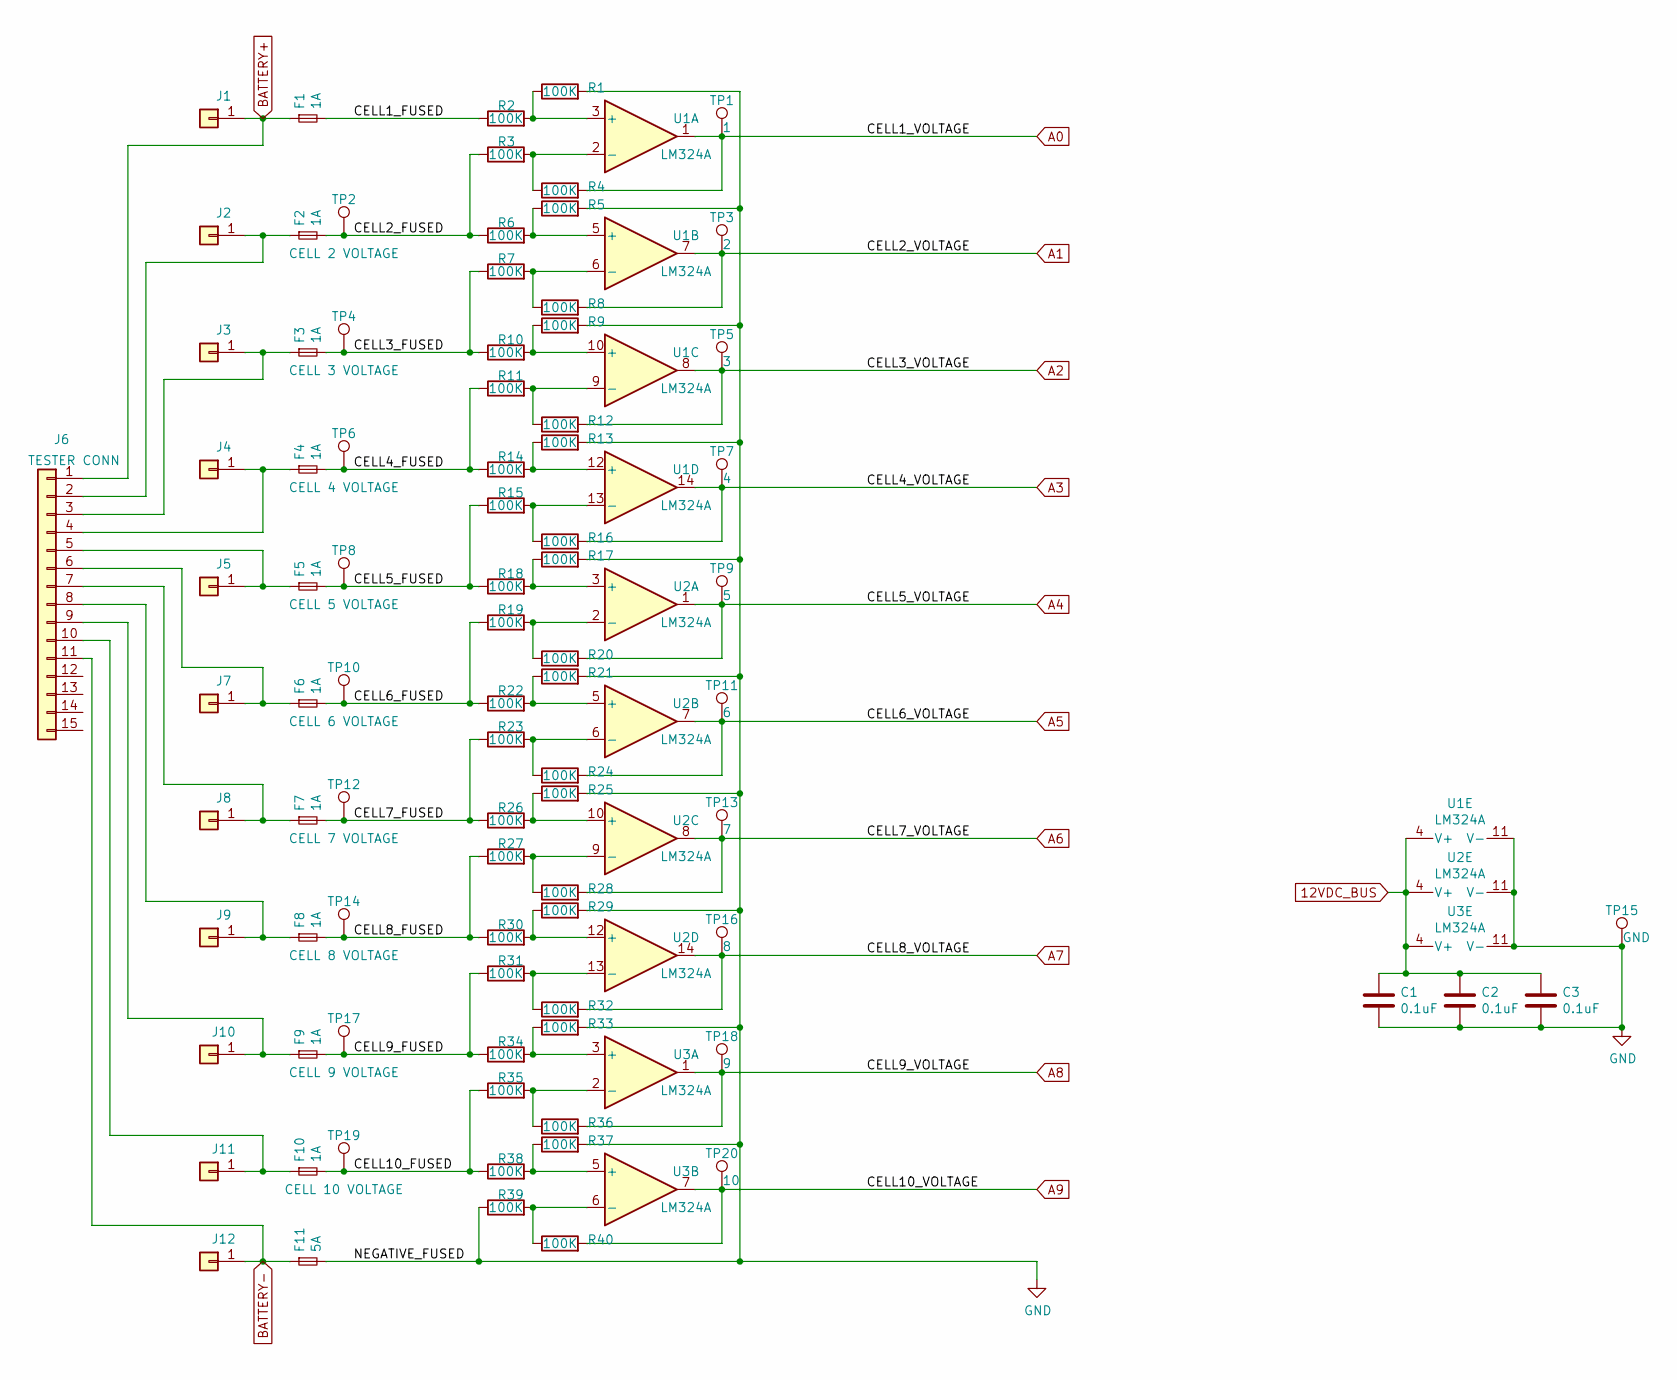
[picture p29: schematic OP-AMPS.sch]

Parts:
C1, C2, C3: 0.1uF; C_1206_3216Metric_Pad1.42x1.75mm_HandSolder; LCSC C24497
F1, F2, F3, F4, F5, F6, F7, F8, F9, F10: 1A; 1206_FUSE
F11: 5A; 1206_FUSE
J1: Conn_01x01; BATTERY_POWER_CONNECTION
J2, J3, J4, J5, J7, J8, J9, J10, J11: Conn_01x01; KEYSTONE_240
J6: TESTER CONN; 15-PIN-DSUB
J12: Conn_01x01; BATTERY_POWER_CONNECTION_WIDE
R1, R2, R3, R4, R5, R6, R7, R8, R9, R10, R11, R12, R13, R14, R15, R16, R17, R18, R19, R20, R21, R22, R23, R24, R25, R26, R27, R28, R29, R30, R31, R32, R33, R34, R35, R36, R37, R38, R39, R40: 100K; R_1206_3216Metric_Pad1.42x1.75mm_HandSolder; LCSC C17900
TP1: 1; TestPoint_THTPad_D4.0mm_Drill2.0mm
TP2: CELL 2 VOLTAGE; TestPoint_Plated_Hole_D3.0mm
TP3: 2; TestPoint_THTPad_D4.0mm_Drill2.0mm
TP4: CELL 3 VOLTAGE; TestPoint_Plated_Hole_D3.0mm
TP5: 3; TestPoint_THTPad_D4.0mm_Drill2.0mm
TP6: CELL 4 VOLTAGE; TestPoint_Plated_Hole_D3.0mm
TP7: 4; TestPoint_THTPad_D4.0mm_Drill2.0mm
TP8: CELL 5 VOLTAGE; TestPoint_Plated_Hole_D3.0mm
TP9: 5; TestPoint_THTPad_D4.0mm_Drill2.0mm
TP10: CELL 6 VOLTAGE; TestPoint_Plated_Hole_D3.0mm
TP11: 6; TestPoint_THTPad_D4.0mm_Drill2.0mm
TP12: CELL 7 VOLTAGE; TestPoint_Plated_Hole_D3.0mm
TP13: 7; TestPoint_THTPad_D4.0mm_Drill2.0mm
TP14: CELL 8 VOLTAGE; TestPoint_Plated_Hole_D3.0mm
TP15: GND; TestPoint_Bridge_Pitch7.62mm_Drill1.3mm
TP16: 8; TestPoint_THTPad_D4.0mm_Drill2.0mm
TP17: CELL 9 VOLTAGE; TestPoint_Plated_Hole_D3.0mm
TP18: 9; TestPoint_THTPad_D4.0mm_Drill2.0mm
TP19: CELL 10 VOLTAGE; TestPoint_Plated_Hole_D3.0mm
TP20: 10; TestPoint_THTPad_D4.0mm_Drill2.0mm
U1, U2, U3: LM324A; DIP-14_W7.62mm_LongPads

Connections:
12VDC_BUS: C1.1, C2.1, C3.1, U1.4 (V+), U2.4 (V+), U3.4 (V+); also elsewhere on the board
/OP-AMPS/CELL1_FUSED: F1.2, R2.1
/OP-AMPS/CELL2_FUSED: F2.2, R3.1, R6.1, TP2.1
/OP-AMPS/CELL3_FUSED: F3.2, R7.1, R10.1, TP4.1
/OP-AMPS/CELL4_FUSED: F4.2, R11.1, R14.1, TP6.1
/OP-AMPS/CELL5_FUSED: F5.2, R15.1, R18.1, TP8.1
/OP-AMPS/CELL6_FUSED: F6.2, R19.1, R22.1, TP10.1
/OP-AMPS/CELL7_FUSED: F7.2, R23.1, R26.1, TP12.1
/OP-AMPS/CELL8_FUSED: F8.2, R27.1, R30.1, TP14.1
/OP-AMPS/CELL9_FUSED: F9.2, R31.1, R34.1, TP17.1
/OP-AMPS/CELL10_FUSED: F10.2, R35.1, R38.1, TP19.1
A0: R4.2, TP1.1, U1.1; also elsewhere on the board
A1: R8.2, TP3.1, U1.7; also elsewhere on the board
A2: R12.2, TP5.1, U1.8; also elsewhere on the board
A3: R16.2, TP7.1, U1.14; also elsewhere on the board
A4: R20.2, TP9.1, U2.1; also elsewhere on the board
A5: R24.2, TP11.1, U2.7; also elsewhere on the board
A6: R28.2, TP13.1, U2.8; also elsewhere on the board
A7: R32.2, TP16.1, U2.14; also elsewhere on the board
A8: R36.2, TP18.1, U3.1; also elsewhere on the board
A9: R40.2, TP20.1, U3.7; also elsewhere on the board
BATTERY+: F1.1, J1.1, J6.1; also elsewhere on the board
BATTERY-: F11.1, J6.11, J12.1
GND: C1.2, C2.2, C3.2, F11.2, R1.2, R5.2, R9.2, R13.2, R17.2, R21.2, R25.2, R29.2, R33.2, R37.2, R39.1, TP15.1, U1.11 (V-), U2.11 (V-), U3.11 (V-); also elsewhere on the board
unnamed: F2.1, J2.1, J6.2
unnamed: F3.1, J3.1, J6.3
unnamed: F4.1, J4.1, J6.4
unnamed: F5.1, J5.1, J6.5
unnamed: F6.1, J6.6, J7.1
unnamed: F7.1, J6.7, J8.1
unnamed: F8.1, J6.8, J9.1
unnamed: F9.1, J6.9, J10.1
unnamed: F10.1, J6.10, J11.1
unnamed: R1.1, R2.2, U1.3 (+)
unnamed: R3.2, R4.1, U1.2 (-)
unnamed: R5.1, R6.2, U1.5 (+)
unnamed: R7.2, R8.1, U1.6 (-)
unnamed: R9.1, R10.2, U1.10 (+)
unnamed: R11.2, R12.1, U1.9 (-)
unnamed: R13.1, R14.2, U1.12 (+)
unnamed: R15.2, R16.1, U1.13 (-)
unnamed: R17.1, R18.2, U2.3 (+)
unnamed: R19.2, R20.1, U2.2 (-)
unnamed: R21.1, R22.2, U2.5 (+)
unnamed: R23.2, R24.1, U2.6 (-)
unnamed: R25.1, R26.2, U2.10 (+)
unnamed: R27.2, R28.1, U2.9 (-)
unnamed: R29.1, R30.2, U2.12 (+)
unnamed: R31.2, R32.1, U2.13 (-)
unnamed: R33.1, R34.2, U3.3 (+)
unnamed: R35.2, R36.1, U3.2 (-)
unnamed: R37.1, R38.2, U3.5 (+)
unnamed: R39.2, R40.1, U3.6 (-)

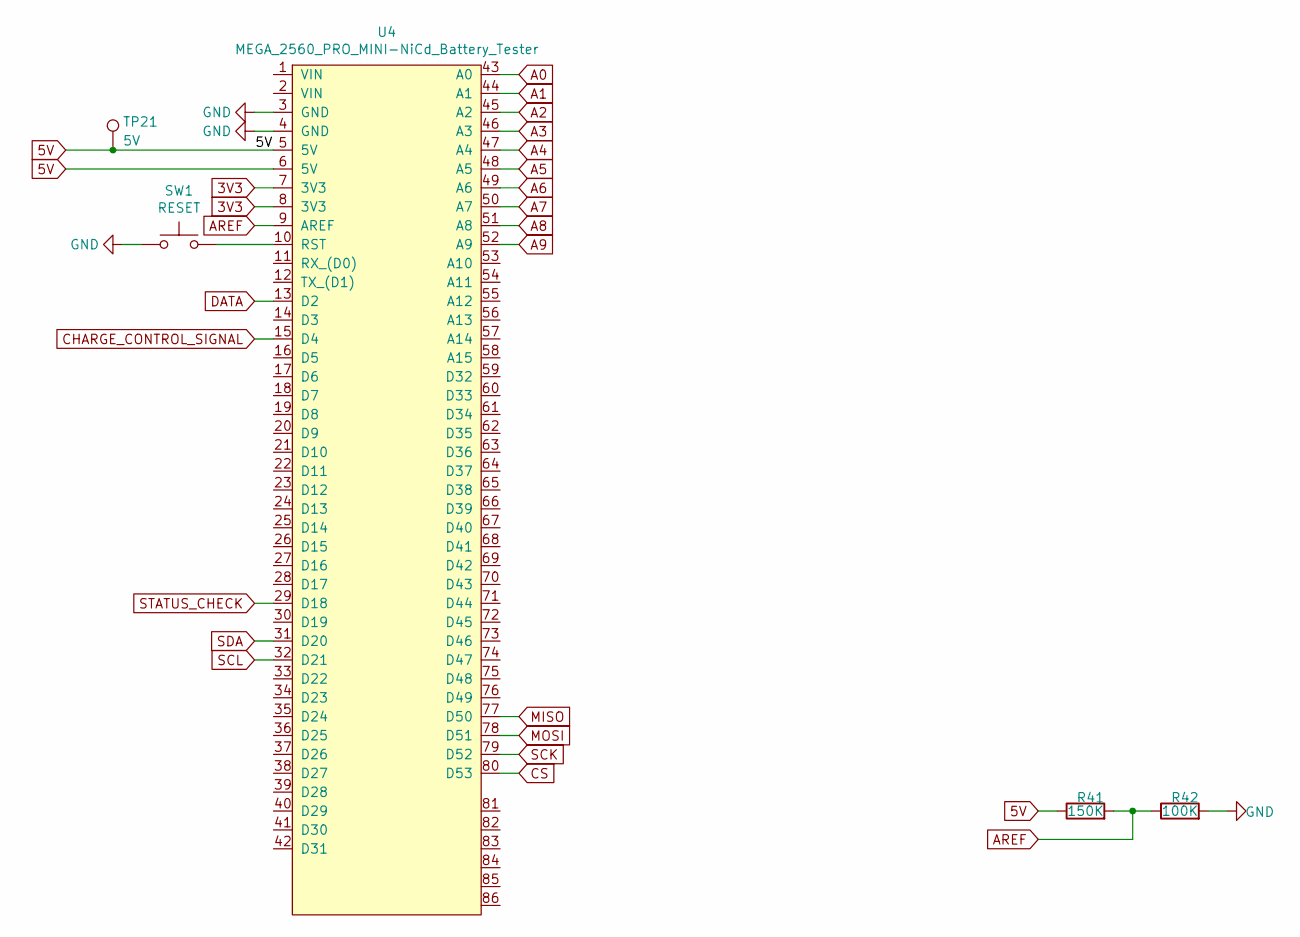
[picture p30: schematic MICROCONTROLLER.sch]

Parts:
R41: 150K; R_1206_3216Metric_Pad1.42x1.75mm_HandSolder; LCSC C17916
R42: 100K; R_1206_3216Metric_Pad1.42x1.75mm_HandSolder; LCSC C17900
SW1: RESET; SW_PUSH_6mm_H5mm
TP21: 5V; TestPoint_THTPad_D4.0mm_Drill2.0mm
U4: MEGA_2560_PRO_MINI-NiCd_Battery_Tester; MEGA 2560 PRO MINI_NO_MOUNTS

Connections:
3V3: U4.7 (3V3), U4.8 (3V3)
5V: R41.1, TP21.1, U4.5 (5V), U4.6 (5V); also elsewhere on the board
A0: U4.43 (A0); also elsewhere on the board
A1: U4.44 (A1); also elsewhere on the board
A2: U4.45 (A2); also elsewhere on the board
A3: U4.46 (A3); also elsewhere on the board
A4: U4.47 (A4); also elsewhere on the board
A5: U4.48 (A5); also elsewhere on the board
A6: U4.49 (A6); also elsewhere on the board
A7: U4.50 (A7); also elsewhere on the board
A8: U4.51 (A8); also elsewhere on the board
A9: U4.52 (A9); also elsewhere on the board
AREF: R41.2, R42.1, U4.9 (AREF)
CHARGE_CONTROL_SIGNAL: U4.15 (D4); also elsewhere on the board
CS: U4.80 (D53); also elsewhere on the board
DATA: U4.13 (D2); also elsewhere on the board
GND: R42.2, SW1.1, U4.3 (GND), U4.4 (GND); also elsewhere on the board
MISO: U4.77 (D50); also elsewhere on the board
MOSI: U4.78 (D51); also elsewhere on the board
unnamed: SW1.2, U4.10 (RST)
SCK: U4.79 (D52); also elsewhere on the board
SCL: U4.32 (D21); also elsewhere on the board
SDA: U4.31 (D20); also elsewhere on the board
STATUS_CHECK: U4.29 (D18); also elsewhere on the board

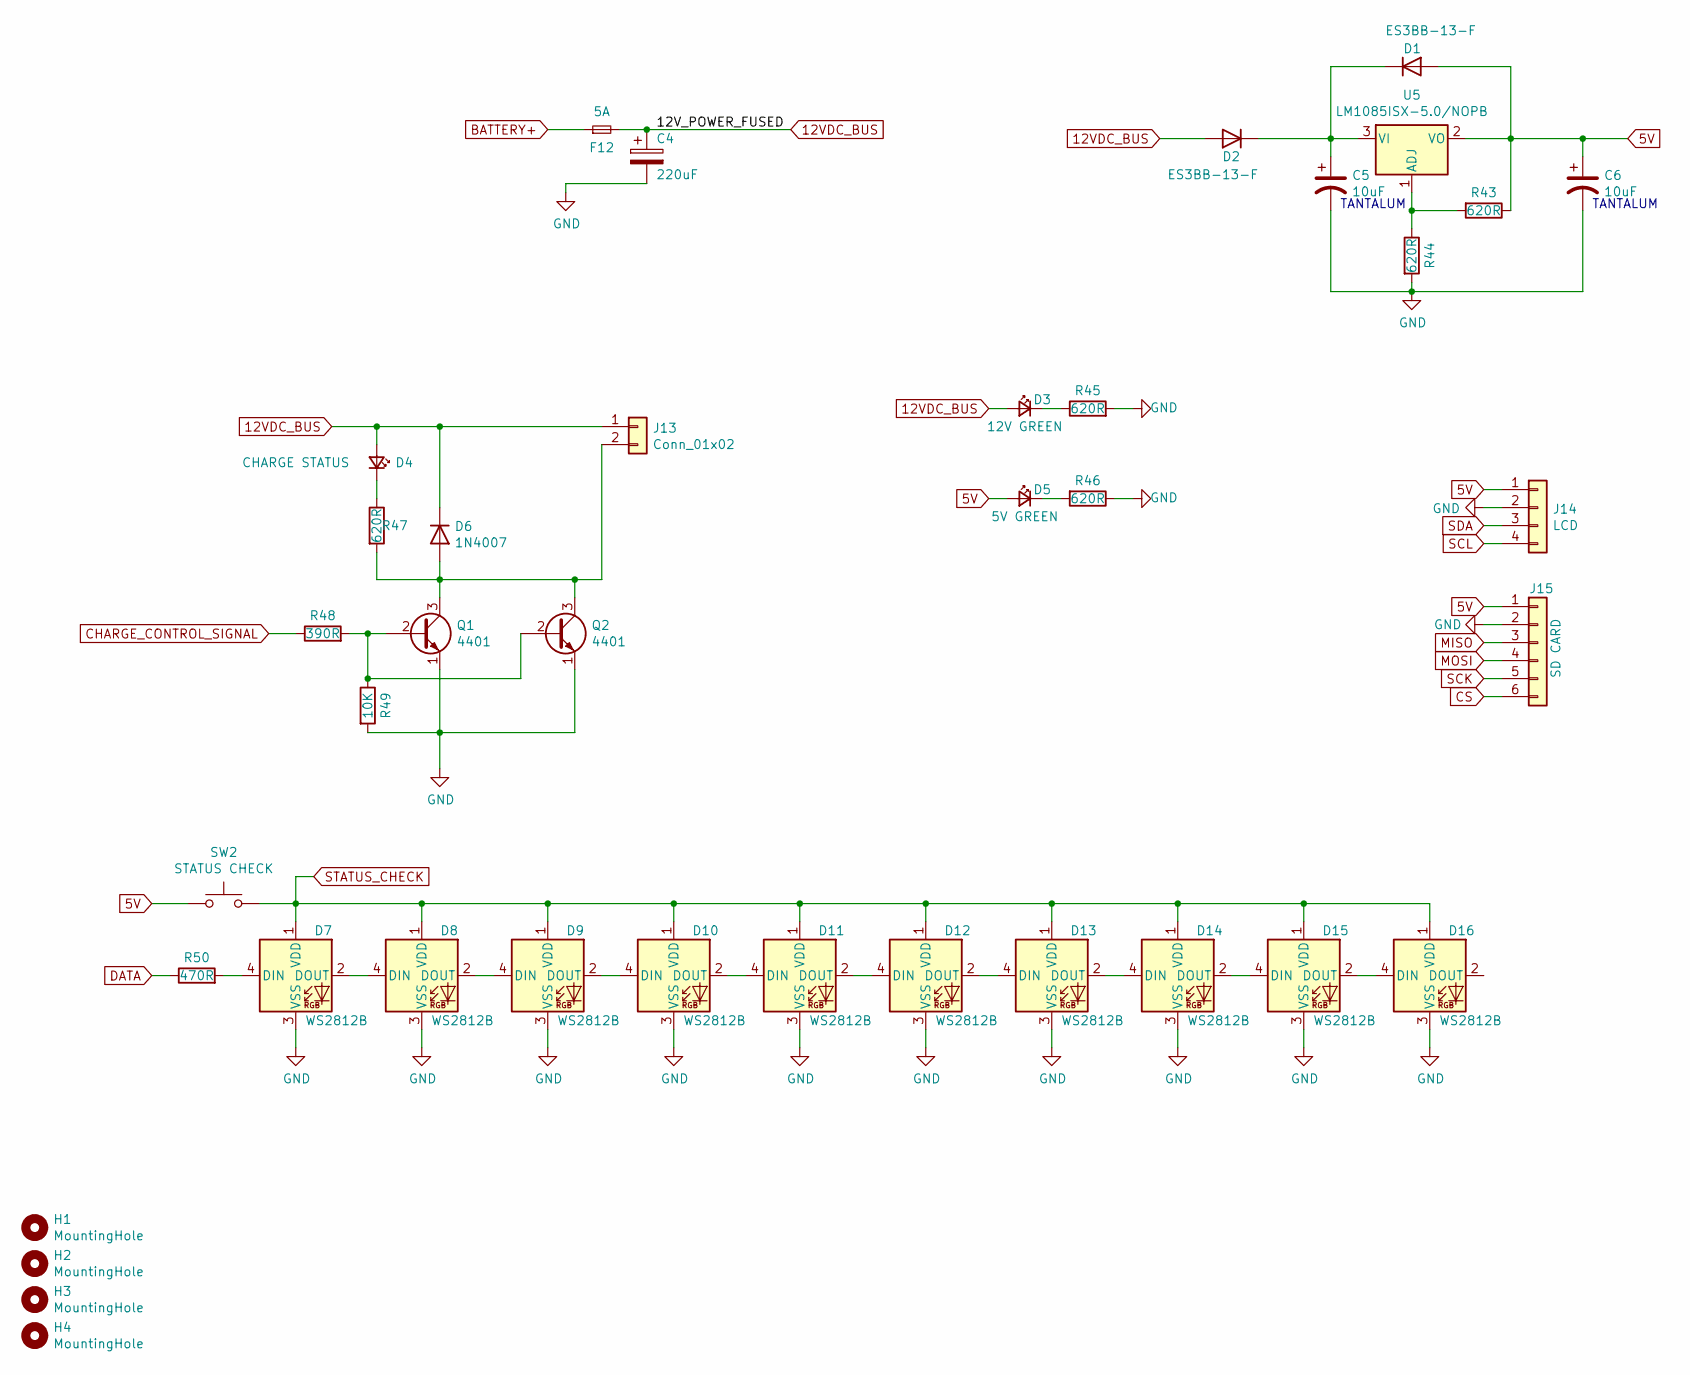
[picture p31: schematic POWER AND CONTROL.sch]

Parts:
C4: 220uF; CP_Radial_D10.0mm_P5.00mm
C5, C6: 10uF; CP_EIA-6032-20_AVX-F_Pad2.25x2.35mm_HandSolder
D1, D2: ES3BB-13-F; D_SMB_Handsoldering
D3: 12V GREEN; LED_D5.0mm_Horizontal_O3.81mm_Z3.0mm
D4: CHARGE STATUS; LED_D5.0mm_Horizontal_O3.81mm_Z3.0mm
D5: 5V GREEN; LED_D5.0mm_Horizontal_O3.81mm_Z3.0mm
D6: 1N4007; D_SMB_Handsoldering
D7, D8, D9, D10, D11, D12, D13, D14, D15, D16: WS2812B; LED_WS2812B_PLCC4_5.0x5.0mm_P3.2mm
F12: 5A; 1206_FUSE
H1, H2, H3, H4: MountingHole; KEYSTONE_7795_SCREW_TERM
J13: Conn_01x02; Molex_Mini-Fit_Jr_5569-02A2_2x01_P4.20mm_Horizontal
J14: LCD; PinHeader_1x04_P2.54mm_Vertical
J15: SD CARD; PinHeader_1x06_P2.54mm_Vertical
Q1: 4401; SOT-23_Handsoldering
Q2: 4401; TO-92L_Inline_Wide
R43, R44, R45, R46, R47: 620R; R_1206_3216Metric_Pad1.42x1.75mm_HandSolder; LCSC C17972
R48: 390R; R_1206_3216Metric_Pad1.42x1.75mm_HandSolder; LCSC C17972
R49: 10K; R_1206_3216Metric_Pad1.42x1.75mm_HandSolder; LCSC C17972
R50: 470R; R_1206_3216Metric_Pad1.42x1.75mm_HandSolder; LCSC C17936
SW2: STATUS CHECK; SW_PUSH_6mm_H5mm
U5: LM1085ISX-5.0/NOPB; TO-263-3_TabPin2

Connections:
5V: C6.1, D1.2 (A), D5.2 (A), J14.1, J15.1, R43.1, SW2.1, U5.2 (VO); also elsewhere on the board
12VDC_BUS: C4.1, D2.2 (A), D3.2 (A), D4.2 (A), D6.1 (K), F12.2, J13.1; also elsewhere on the board
BATTERY+: F12.1; also elsewhere on the board
CHARGE_CONTROL_SIGNAL: R48.1; also elsewhere on the board
CS: J15.6; also elsewhere on the board
DATA: R50.1; also elsewhere on the board
GND: C4.2, C5.2, C6.2, D7.3 (VSS), D8.3 (VSS), D9.3 (VSS), D10.3 (VSS), D11.3 (VSS), D12.3 (VSS), D13.3 (VSS), D14.3 (VSS), D15.3 (VSS), D16.3 (VSS), J14.2, J15.2, Q1.1 (E), Q2.1 (E), R44.2, R45.2, R46.1, R49.2; also elsewhere on the board
MISO: J15.3; also elsewhere on the board
MOSI: J15.4; also elsewhere on the board
unnamed: C5.1, D1.1 (K), D2.1 (K), U5.3 (VI)
unnamed: D3.1 (K), R45.1
unnamed: D4.1 (K), R47.1
unnamed: D5.1 (K), R46.2
unnamed: D6.2 (A), J13.2, Q1.3 (C), Q2.3 (C), R47.2
unnamed: D7.2 (DOUT), D8.4 (DIN)
unnamed: D7.4 (DIN), R50.2
unnamed: D8.2 (DOUT), D9.4 (DIN)
unnamed: D10.2 (DOUT), D11.4 (DIN)
unnamed: D9.2 (DOUT), D10.4 (DIN)
unnamed: D11.2 (DOUT), D12.4 (DIN)
unnamed: D12.2 (DOUT), D13.4 (DIN)
unnamed: D13.2 (DOUT), D14.4 (DIN)
unnamed: D14.2 (DOUT), D15.4 (DIN)
unnamed: D15.2 (DOUT), D16.4 (DIN)
unnamed: Q1.2 (B), Q2.2 (B), R48.2, R49.1
unnamed: R43.2, R44.1, U5.1 (ADJ)
SCK: J15.5; also elsewhere on the board
SCL: J14.4; also elsewhere on the board
SDA: J14.3; also elsewhere on the board
STATUS_CHECK: D7.1 (VDD), D8.1 (VDD), D9.1 (VDD), D10.1 (VDD), D11.1 (VDD), D12.1 (VDD), D13.1 (VDD), D14.1 (VDD), D15.1 (VDD), D16.1 (VDD), SW2.2; also elsewhere on the board

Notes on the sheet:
TANTALUM

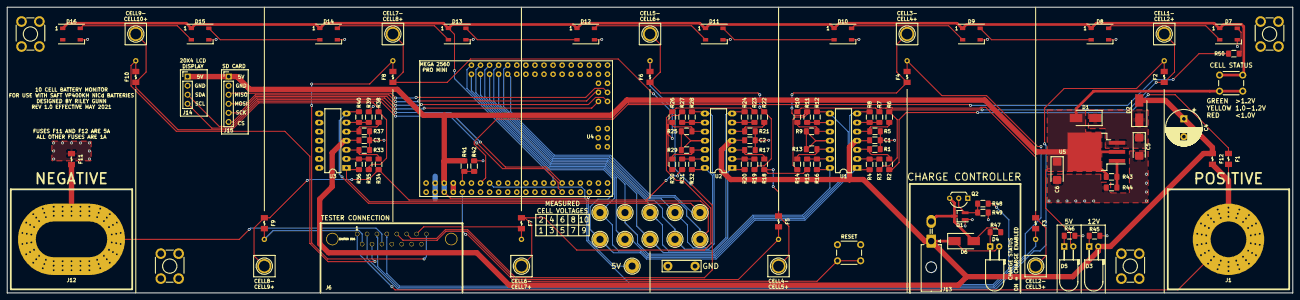
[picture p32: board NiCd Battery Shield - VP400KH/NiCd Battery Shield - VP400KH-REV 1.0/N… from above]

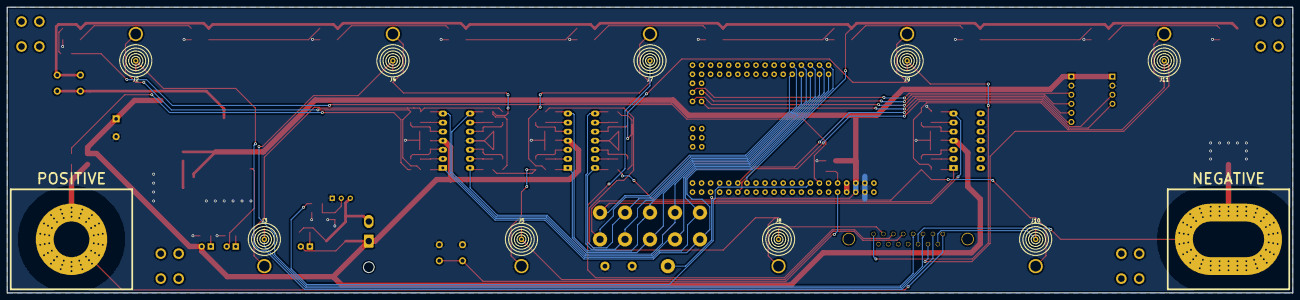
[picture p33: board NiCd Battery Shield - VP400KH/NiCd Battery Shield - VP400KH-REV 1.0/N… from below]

Board: 2 copper layers, 360.0 x 80.0 mm, 133 parts (9 on the bottom side), 83 nets.

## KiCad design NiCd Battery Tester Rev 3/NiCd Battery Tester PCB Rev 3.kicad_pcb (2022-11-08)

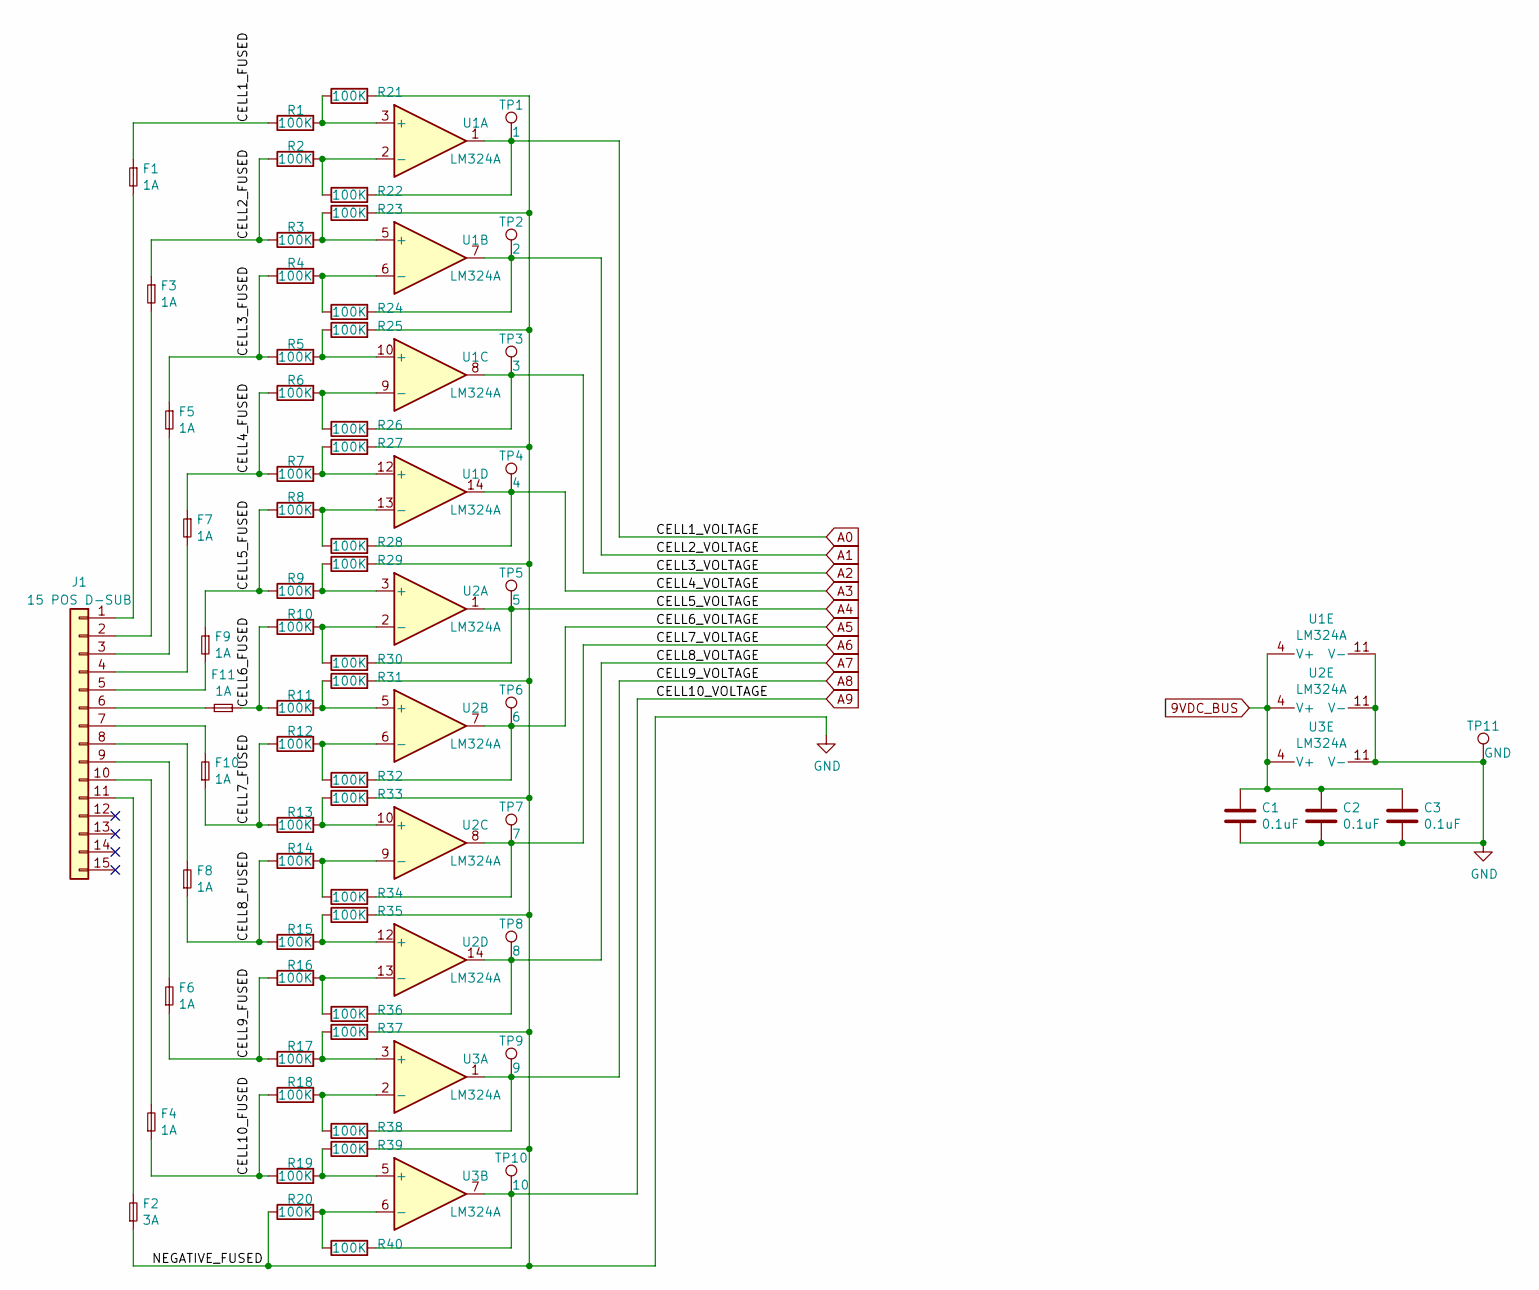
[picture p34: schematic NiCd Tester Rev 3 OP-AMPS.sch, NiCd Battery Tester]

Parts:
C1, C2, C3: 0.1uF; C_1206_3216Metric_Pad1.42x1.75mm_HandSolder; LCSC C24497
F1, F3, F4, F5, F6, F7, F8, F9, F10, F11: 1A; 1206_FUSE
F2: 3A; 1206_FUSE
J1: 15 POS D-SUB; ADAM_TECH_DA15-SL-25
R1, R2, R3, R4, R5, R6, R7, R8, R9, R10, R11, R12, R13, R14, R15, R16, R17, R18, R19, R20, R21, R22, R23, R24, R25, R26, R27, R28, R29, R30, R31, R32, R33, R34, R35, R36, R37, R38, R39, R40: 100K; R_1206_3216Metric_Pad1.42x1.75mm_HandSolder; LCSC C17900
TP1: 1; TestPoint_THTPad_D1.5mm_Drill0.7mm
TP2: 2; TestPoint_THTPad_D1.5mm_Drill0.7mm
TP3: 3; TestPoint_THTPad_D1.5mm_Drill0.7mm
TP4: 4; TestPoint_THTPad_D1.5mm_Drill0.7mm
TP5: 5; TestPoint_THTPad_D1.5mm_Drill0.7mm
TP6: 6; TestPoint_THTPad_D1.5mm_Drill0.7mm
TP7: 7; TestPoint_THTPad_D1.5mm_Drill0.7mm
TP8: 8; TestPoint_THTPad_D1.5mm_Drill0.7mm
TP9: 9; TestPoint_THTPad_D1.5mm_Drill0.7mm
TP10: 10; TestPoint_THTPad_D1.5mm_Drill0.7mm
TP11: GND; TestPoint_THTPad_D1.5mm_Drill0.7mm
U1, U2, U3: LM324A; DIP-14_W7.62mm_LongPads

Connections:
9VDC_BUS: C1.1, C2.1, C3.1, U1.4 (V+), U2.4 (V+), U3.4 (V+); also elsewhere on the board
/OP-AMPS/CELL1_FUSED: F1.1, R1.1
/OP-AMPS/CELL2_FUSED: F3.1, R2.1, R3.1
/OP-AMPS/CELL3_FUSED: F5.1, R4.1, R5.1
/OP-AMPS/CELL4_FUSED: F7.1, R6.1, R7.1
/OP-AMPS/CELL5_FUSED: F9.1, R8.1, R9.1
/OP-AMPS/CELL6_FUSED: F11.1, R10.1, R11.1
/OP-AMPS/CELL7_FUSED: F10.1, R12.1, R13.1
/OP-AMPS/CELL8_FUSED: F8.1, R14.1, R15.1
/OP-AMPS/CELL9_FUSED: F6.1, R16.1, R17.1
/OP-AMPS/CELL10_FUSED: F4.1, R18.1, R19.1
A0: R22.2, TP1.1, U1.1; also elsewhere on the board
A1: R24.2, TP2.1, U1.7; also elsewhere on the board
A2: R26.2, TP3.1, U1.8; also elsewhere on the board
A3: R28.2, TP4.1, U1.14; also elsewhere on the board
A4: R30.2, TP5.1, U2.1; also elsewhere on the board
A5: R32.2, TP6.1, U2.7; also elsewhere on the board
A6: R34.2, TP7.1, U2.8; also elsewhere on the board
A7: R36.2, TP8.1, U2.14; also elsewhere on the board
A8: R38.2, TP9.1, U3.1; also elsewhere on the board
A9: R40.2, TP10.1, U3.7; also elsewhere on the board
GND: C1.2, C2.2, C3.2, F2.1, R20.1, R21.2, R23.2, R25.2, R27.2, R29.2, R31.2, R33.2, R35.2, R37.2, R39.2, TP11.1, U1.11 (V-), U2.11 (V-), U3.11 (V-); also elsewhere on the board
unnamed: F1.2, J1.1
unnamed: F2.2, J1.11
unnamed: F3.2, J1.2
unnamed: F4.2, J1.10
unnamed: F5.2, J1.3
unnamed: F6.2, J1.9
unnamed: F7.2, J1.4
unnamed: F8.2, J1.8
unnamed: F9.2, J1.5
unnamed: F10.2, J1.7
unnamed: F11.2, J1.6
unnamed: R1.2, R21.1, U1.3 (+)
unnamed: R2.2, R22.1, U1.2 (-)
unnamed: R10.2, R30.1, U2.2 (-)
unnamed: R11.2, R31.1, U2.5 (+)
unnamed: R12.2, R32.1, U2.6 (-)
unnamed: R13.2, R33.1, U2.10 (+)
unnamed: R14.2, R34.1, U2.9 (-)
unnamed: R15.2, R35.1, U2.12 (+)
unnamed: R16.2, R36.1, U2.13 (-)
unnamed: R17.2, R37.1, U3.3 (+)
unnamed: R18.2, R38.1, U3.2 (-)
unnamed: R19.2, R39.1, U3.5 (+)
unnamed: R20.2, R40.1, U3.6 (-)
unnamed: R3.2, R23.1, U1.5 (+)
unnamed: R4.2, R24.1, U1.6 (-)
unnamed: R5.2, R25.1, U1.10 (+)
unnamed: R6.2, R26.1, U1.9 (-)
unnamed: R7.2, R27.1, U1.12 (+)
unnamed: R8.2, R28.1, U1.13 (-)
unnamed: R9.2, R29.1, U2.3 (+)

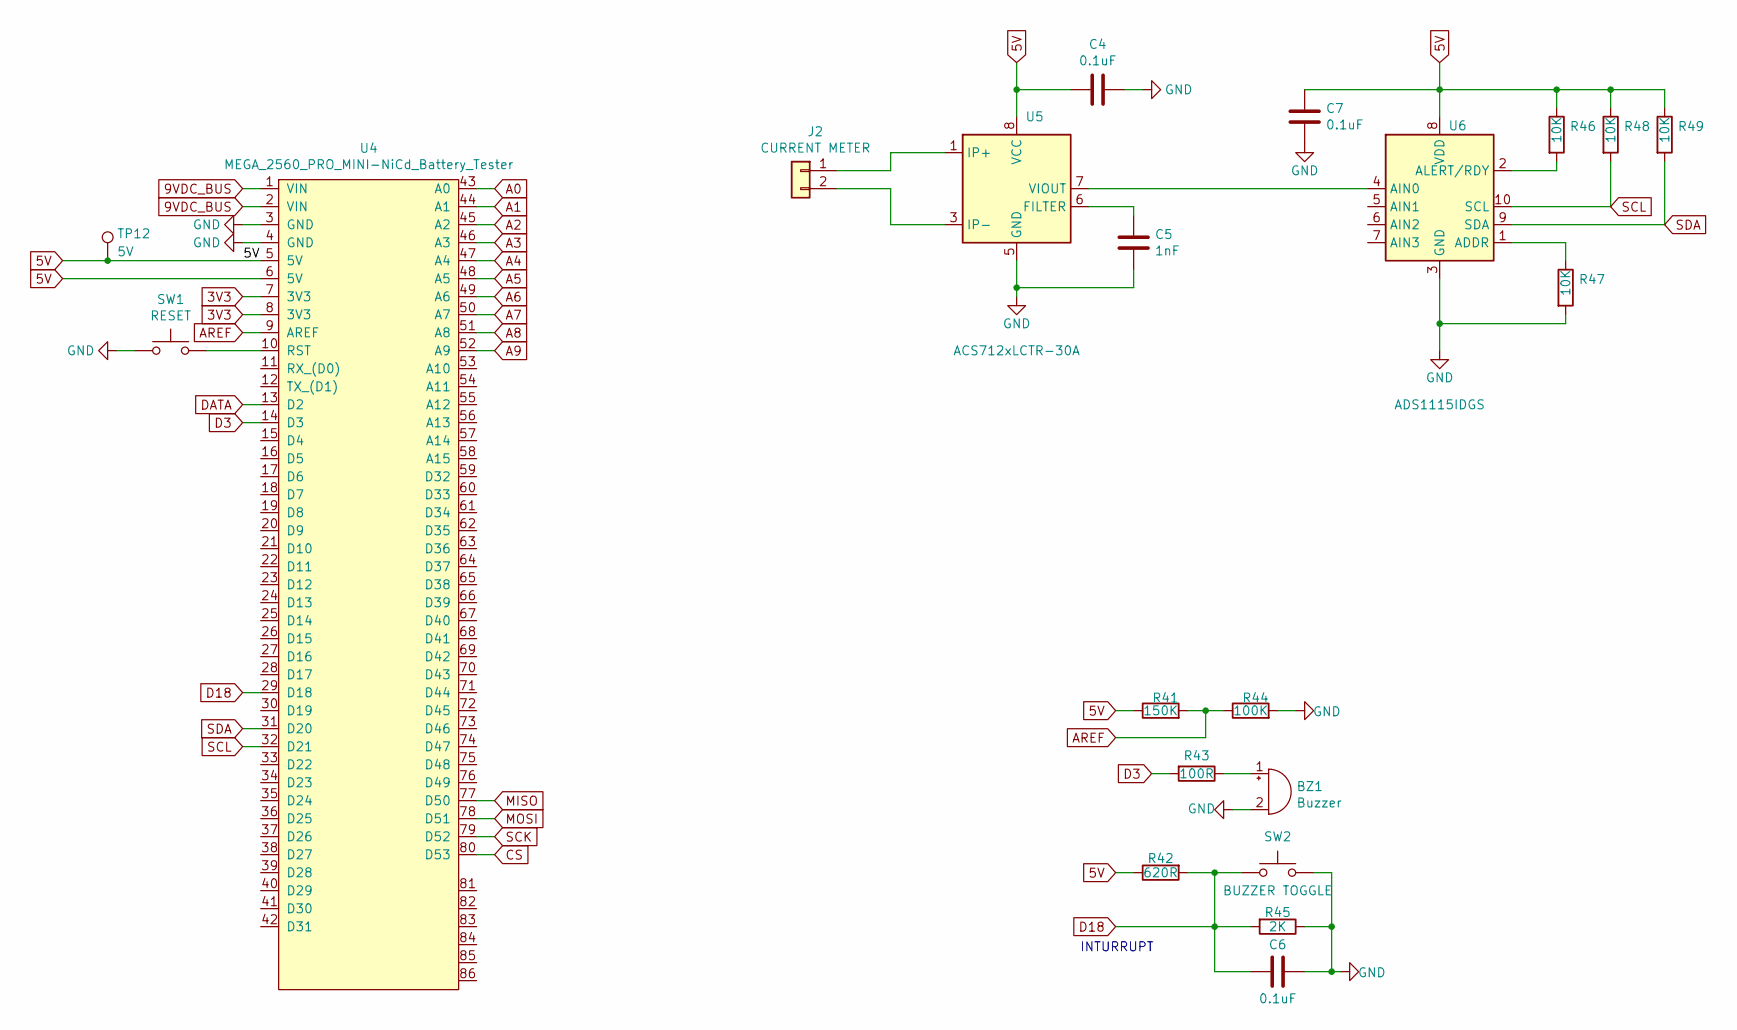
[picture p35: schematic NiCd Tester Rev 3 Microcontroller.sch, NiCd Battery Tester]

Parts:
BZ1: Buzzer; BUZZER_12mm
C4, C7: 0.1uF; C_1206_3216Metric_Pad1.42x1.75mm_HandSolder; LCSC C24497
C5: 1nF; C_1206_3216Metric_Pad1.42x1.75mm_HandSolder; LCSC C35216
C6: 0.1uF; CP_Radial_D5.0mm_P2.50mm
J2: CURRENT METER; CUI_TB005-762-02BE
R41: 150K; R_1206_3216Metric_Pad1.42x1.75mm_HandSolder; LCSC C17916
R42: 620R; R_1206_3216Metric_Pad1.42x1.75mm_HandSolder; LCSC C17972
R43: 100R; R_1206_3216Metric_Pad1.42x1.75mm_HandSolder; LCSC C17901
R44: 100K; R_1206_3216Metric_Pad1.42x1.75mm_HandSolder; LCSC C17900
R45: 2K; R_1206_3216Metric_Pad1.42x1.75mm_HandSolder; LCSC C17944
R46, R47, R48, R49: 10K; R_1206_3216Metric_Pad1.42x1.75mm_HandSolder; LCSC C17902
SW1: RESET; SW_PUSH_6mm_H5mm
SW2: BUZZER TOGGLE; SW_PUSH_6mm_H5mm
TP12: 5V; TestPoint_THTPad_D1.5mm_Drill0.7mm
U4: MEGA_2560_PRO_MINI-NiCd_Battery_Tester; MEGA 2560 PRO MINI_NO_MOUNTS
U5: ACS712xLCTR-30A; SOIC-8_3.9x4.9mm_P1.27mm; LCSC C9932
U6: ADS1115IDGS; MSOP-10_3x3mm_P0.5mm; LCSC C37593

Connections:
3V3: U4.7 (3V3), U4.8 (3V3)
5V: C4.2, C7.2, R41.1, R42.1, R46.1, R48.1, R49.1, TP12.1, U4.5 (5V), U4.6 (5V), U5.8 (VCC), U6.8 (VDD); also elsewhere on the board
9VDC_BUS: U4.1 (VIN), U4.2 (VIN); also elsewhere on the board
A0: U4.43 (A0); also elsewhere on the board
A1: U4.44 (A1); also elsewhere on the board
A2: U4.45 (A2); also elsewhere on the board
A3: U4.46 (A3); also elsewhere on the board
A4: U4.47 (A4); also elsewhere on the board
A5: U4.48 (A5); also elsewhere on the board
A6: U4.49 (A6); also elsewhere on the board
A7: U4.50 (A7); also elsewhere on the board
A8: U4.51 (A8); also elsewhere on the board
A9: U4.52 (A9); also elsewhere on the board
AREF: R41.2, R44.1, U4.9 (AREF)
CS: U4.80 (D53); also elsewhere on the board
D3: R43.2, U4.14 (D3)
D18: C6.2, R42.2, R45.2, SW2.1, U4.29 (D18)
DATA: U4.13 (D2); also elsewhere on the board
GND: BZ1.2 (+), C4.1, C5.1, C6.1, C7.1, R44.2, R45.1, R47.2, SW1.1, SW2.2, U4.3 (GND), U4.4 (GND), U5.5 (GND), U6.3 (GND); also elsewhere on the board
MISO: U4.77 (D50); also elsewhere on the board
MOSI: U4.78 (D51); also elsewhere on the board
unnamed: BZ1.1 (-), R43.1
unnamed: C5.2, U5.6 (FILTER)
unnamed: J2.1, U5.1 (IP+), U5.2 (IP+)
unnamed: J2.2, U5.3 (IP-), U5.4 (IP-)
unnamed: R46.2, U6.2 (ALERT/RDY)
unnamed: R47.1, U6.1 (ADDR)
unnamed: SW1.2, U4.10 (RST)
unnamed: U5.7 (VIOUT), U6.4 (AIN0)
SCK: U4.79 (D52); also elsewhere on the board
SCL: R48.2, U4.32 (D21), U6.10 (SCL); also elsewhere on the board
SDA: R49.2, U4.31 (D20), U6.9 (SDA); also elsewhere on the board

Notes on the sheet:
INTURRUPT

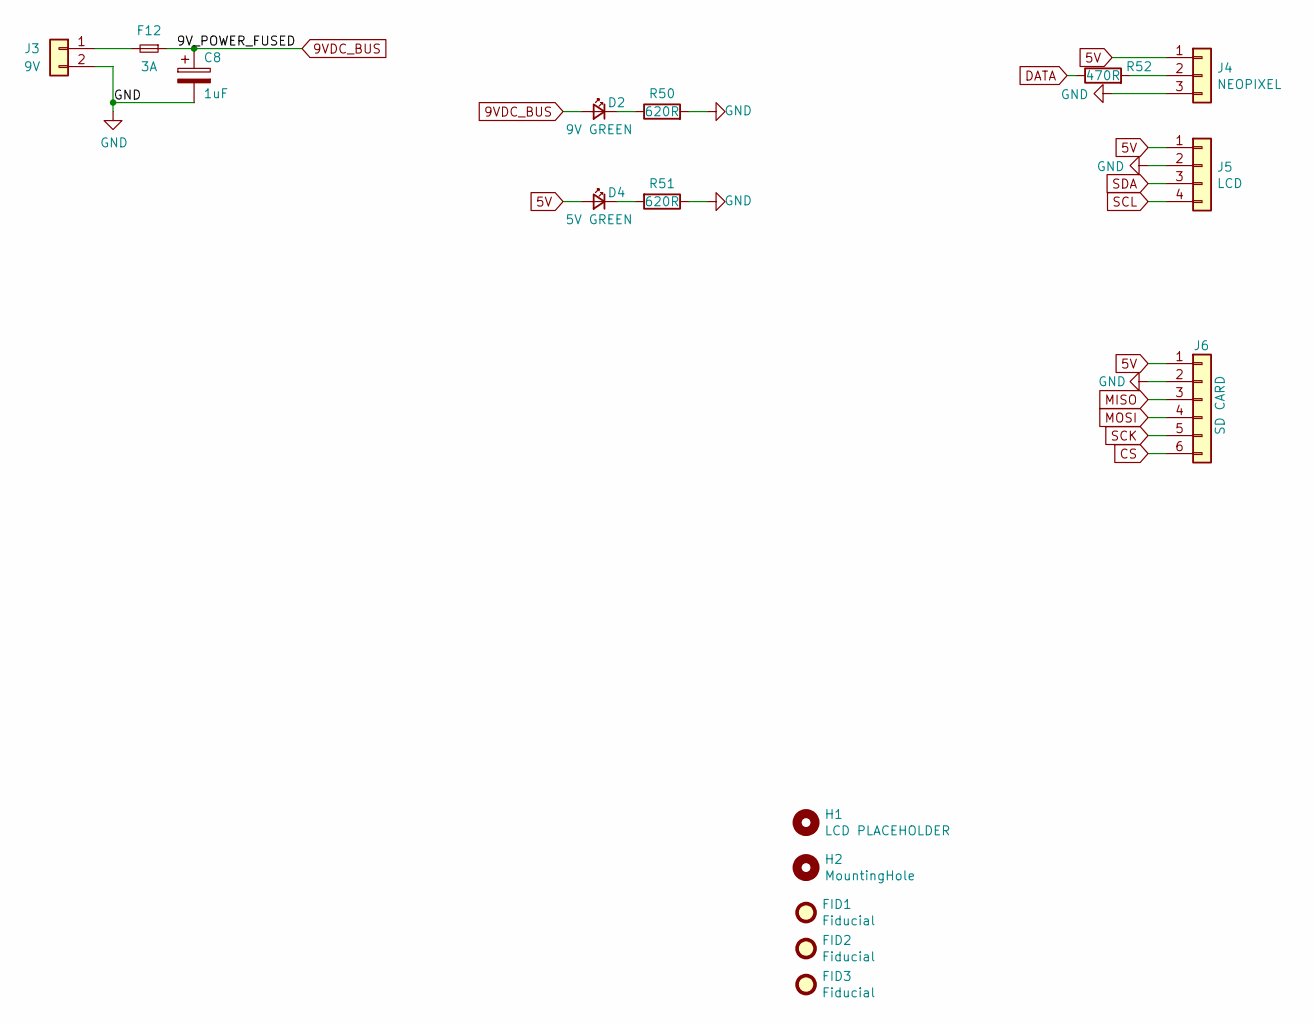
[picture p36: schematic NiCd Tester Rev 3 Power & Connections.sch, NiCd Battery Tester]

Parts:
C8: 1uF; CP_Radial_D5.0mm_P2.50mm
D2: 9V GREEN; LED_D5.0mm
D4: 5V GREEN; LED_D5.0mm
F12: 3A; 1206_FUSE
FID1, FID2, FID3: Fiducial; Fiducial_0.75mm_Mask1.5mm
H1: LCD PLACEHOLDER; 20x4_LCD_BOUNDARY
H2: MountingHole; MountingHole_3.2mm_M3
J3: 9V; BarrelJack_CUI_PJ-102AH_Horizontal
J4: NEOPIXEL; PinHeader_1x03_P2.54mm_Vertical
J5: LCD; PinHeader_1x04_P2.54mm_Vertical
J6: SD CARD; PinHeader_1x06_P2.54mm_Vertical
R50, R51: 620R; R_1206_3216Metric_Pad1.42x1.75mm_HandSolder; LCSC C17972
R52: 470R; R_1206_3216Metric_Pad1.42x1.75mm_HandSolder; LCSC C17936

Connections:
5V: D4.2 (A), J4.1, J5.1, J6.1; also elsewhere on the board
9VDC_BUS: C8.1, D2.2 (A), F12.1; also elsewhere on the board
CS: J6.6; also elsewhere on the board
DATA: R52.1; also elsewhere on the board
GND: C8.2, J3.2, J4.3, J5.2, J6.2, R50.2, R51.1; also elsewhere on the board
MISO: J6.3; also elsewhere on the board
MOSI: J6.4; also elsewhere on the board
unnamed: D2.1 (K), R50.1
unnamed: D4.1 (K), R51.2
unnamed: F12.2, J3.1
unnamed: J4.2, R52.2
SCK: J6.5; also elsewhere on the board
SCL: J5.4; also elsewhere on the board
SDA: J5.3; also elsewhere on the board

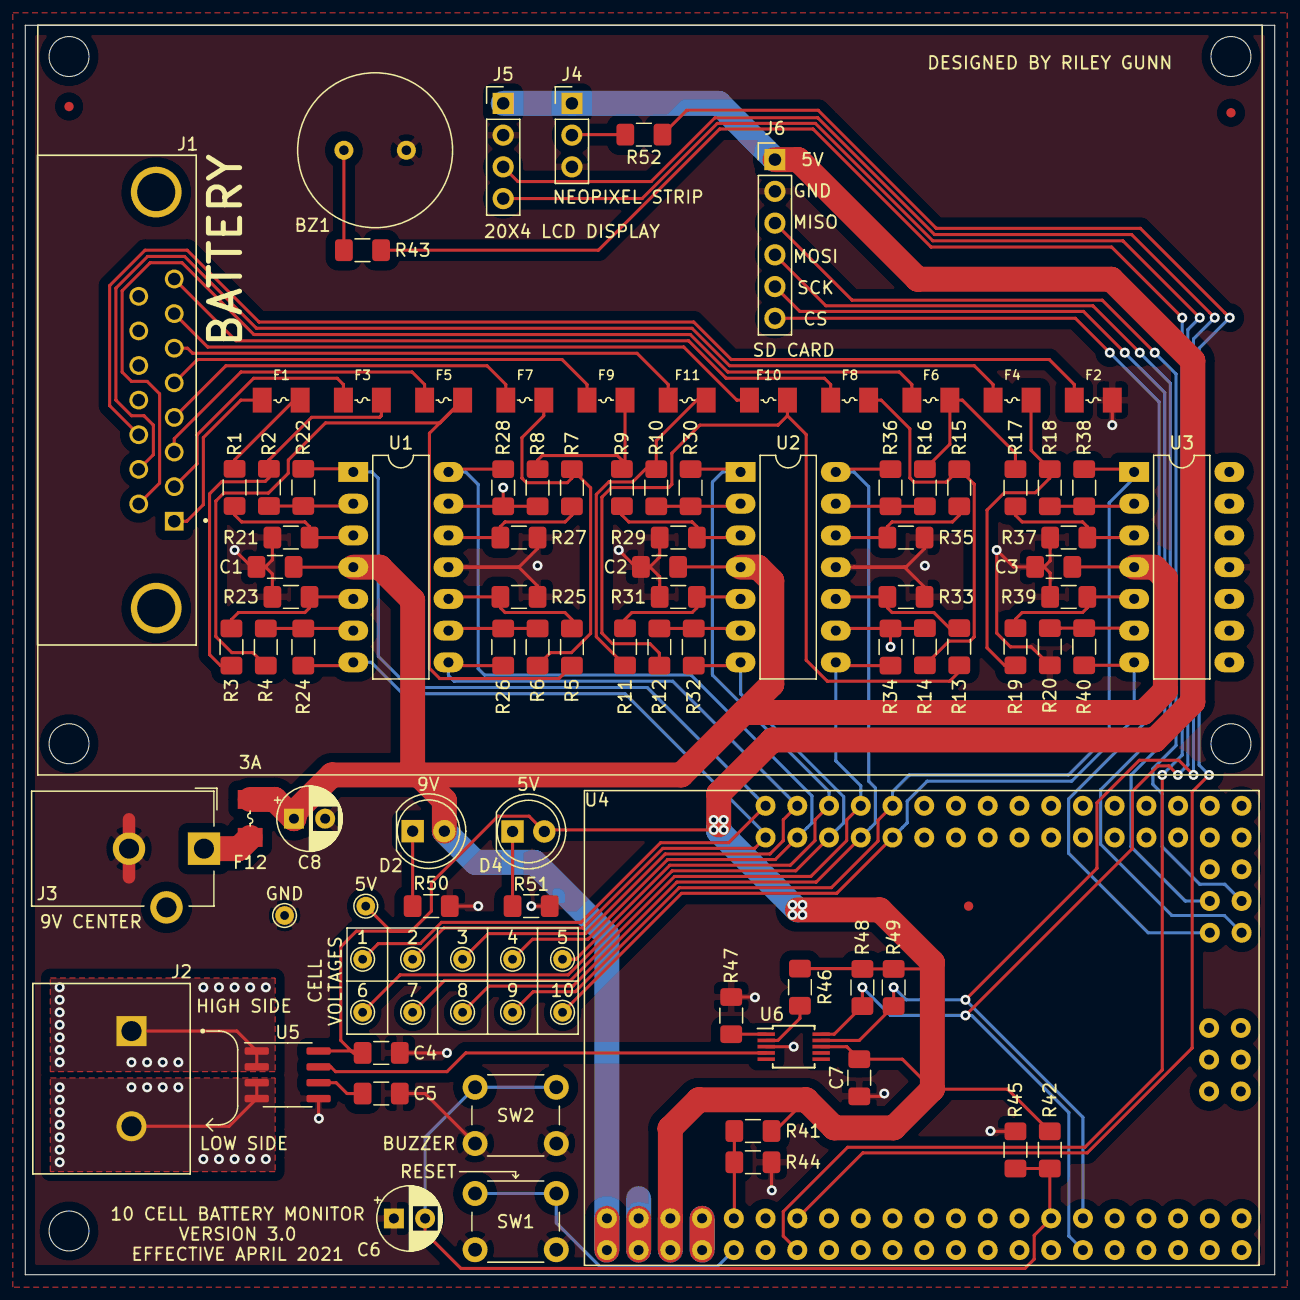
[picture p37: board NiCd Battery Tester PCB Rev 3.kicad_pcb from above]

Board: 2 copper layers, 100.0 x 100.0 mm, 106 parts (0 on the bottom side), 77 nets.

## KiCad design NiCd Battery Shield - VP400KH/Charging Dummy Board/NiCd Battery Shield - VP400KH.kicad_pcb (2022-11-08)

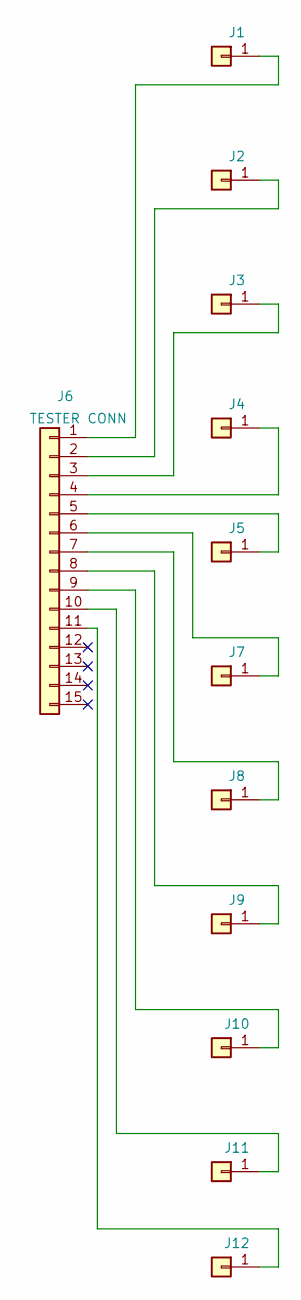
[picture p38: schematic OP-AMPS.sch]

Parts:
J1: Conn_01x01; BATTERY_POWER_CONNECTION
J2, J3, J4, J5, J7, J8, J9, J10, J11: Conn_01x01; KEYSTONE_240
J6: TESTER CONN; 15-PIN-DSUB
J12: Conn_01x01; BATTERY_POWER_CONNECTION_WIDE

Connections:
unnamed: J1.1, J6.1
unnamed: J2.1, J6.2
unnamed: J3.1, J6.3
unnamed: J4.1, J6.4
unnamed: J5.1, J6.5
unnamed: J6.6, J7.1
unnamed: J6.7, J8.1
unnamed: J6.8, J9.1
unnamed: J6.9, J10.1
unnamed: J6.10, J11.1
unnamed: J6.11, J12.1

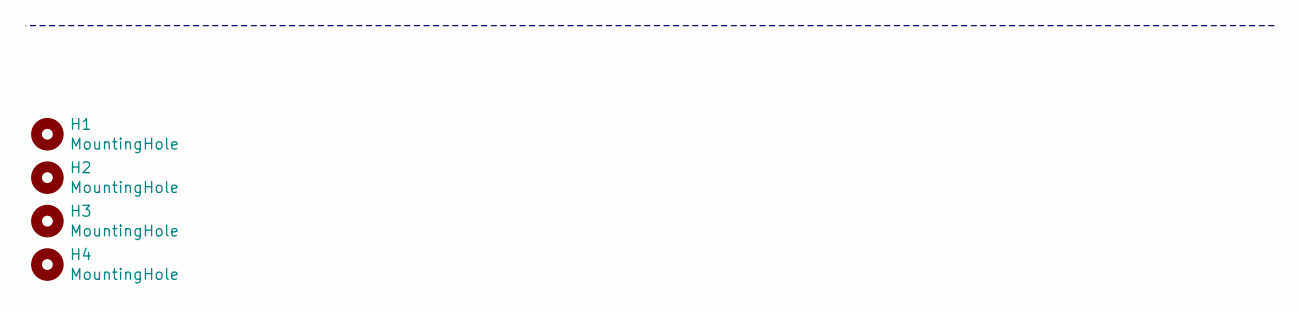
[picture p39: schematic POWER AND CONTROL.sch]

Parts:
H1, H2, H3, H4: MountingHole; KEYSTONE_7795_SCREW_TERM

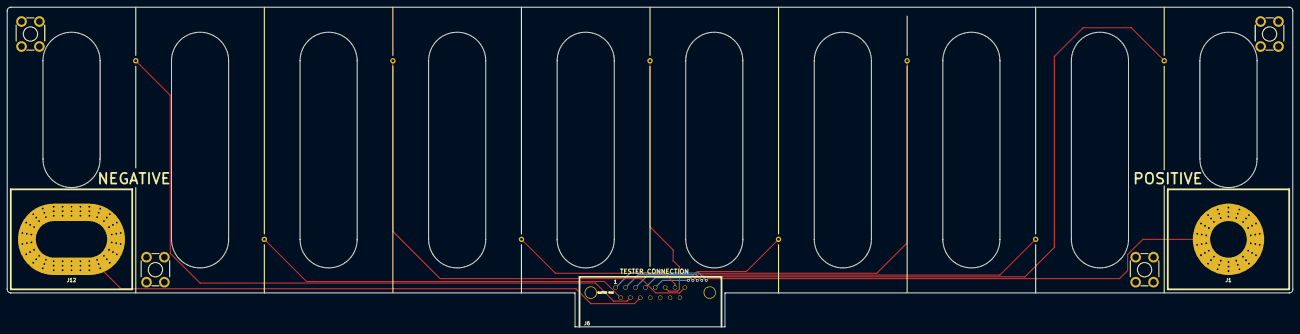
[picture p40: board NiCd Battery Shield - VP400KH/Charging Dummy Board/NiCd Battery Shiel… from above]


Board: 2 copper layers, 360.0 x 89.5 mm, 16 parts (9 on the bottom side), 11 nets.

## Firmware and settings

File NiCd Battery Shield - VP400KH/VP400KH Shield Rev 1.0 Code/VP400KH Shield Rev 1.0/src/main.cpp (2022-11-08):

/*
 * The program is for an arduino MEGA2560 based NiCd battery monitor and data logger
 * 
 * 
 */


// Include libraries needed for the project
#include <Arduino.h>
#include <Wire.h>
#include <LiquidCrystal_I2C.h>
#include <SPI.h>
#include <SD.h>
#include <Adafruit_NeoPixel.h>

File batfile;

// Initialize the LCD display
LiquidCrystal_I2C disp(0x27,20,4);

float GetVoltage(int AnalogInput, float comp);
void SetLEDs ();

// Initialize all the analog ports to be used, BV denotes "Battery Voltage"
// int since the Arduino analog inputs are 10-bit ADCs (1023)
int BV1 = A0;
int BV2 = A1;
int BV3 = A2;
int BV4 = A3;
int BV5 = A4;
int BV6 = A5;
int BV7 = A6;
int BV8 = A7;
int BV9 = A8;
int BV10 = A9;

// Store analog sensors in an array for simplicity with a temp array that may be used for calculations.
int CellVoltages[10] = {BV1, BV2, BV3, BV4, BV5, BV6, BV7, BV8, BV9, BV10};
float tempCellVoltages[10] = {0, 0, 0, 0, 0, 0, 0, 0, 0, 0};
uint32_t CellStat[10] = {0, 0, 0, 0, 0, 0, 0, 0, 0, 0};

// These values are to compensate for the non-matching resistors used for the difference amplifier ((Vx+ - Vx-) /ACTUAL VOLTAGE)
float compensation[10] = {1.0, 1.0, 1.0, 1.0, 1.0, 1.0, 1.0, 1.0, 1.0, 1.0};


// Initialize any digital pins to be used, RelayCont denotes a relay control signal.

int RelayCont = 4;                    // Relay Control

// Initialize any temporary or global values to be used
float temp = 0;                 // Global placeholder
const int numReadings = 10;     // Number of readings for the analog input average function
float analogRef = 2.56;         // Analog reference voltage. This value is set in "SETUP" and is selectable. See Arduino "AREF" documentation
float BatteryVolt = 0;          // Total battery voltage for a 10 cell pack
int Timer = 0;                  // Charge and Discharge Timer
int TimeToggle = 0;             // Timer Toggle
int oldTime = 0;                // placeholder for time
bool ChargeState;               // Placeholder for the charging state
bool LoadState;                 // Placeholder for the loading state

// NeoPixel Strip 
#define LED_PIN 2
#define LED_COUNT 10
Adafruit_NeoPixel strip(LED_COUNT, LED_PIN, NEO_GRB + NEO_KHZ800);

// Setup, runs once.
void setup() {
  
  // Initialize the LCD
  disp.init();
  disp.setBacklight(LOW);

  // Set the Analog Reference Voltage 
  analogReference(INTERNAL2V56);

  // Set up timer
  cli();      // Disable interrrupts

  TCCR4A = 0;   // Set entire TCCR1A register to 0
  TCCR4B = 0;   // Set entire TCCR1B register to 0
  TCNT4 = 0;    // Initialize counter value to 0
  // set compare match register for 1hz increments
  OCR4A = 15624/1;  // (16*10^6) / (1*1024) - 1 (must be <65536)
  // turn on CTC mode
  TCCR4B |= (1 << WGM12);
  // Set CS12 and CS10 bits for 1024 prescaler
  TCCR4B |= (1 << CS12) | (1 << CS10);
  // enable timer compare interrupt
  TIMSK4 |= (1 << OCIE4A);

  sei();      // Enable Interrupts

  // Begin serial communication
  Serial.begin(9600);

  if (!SD.begin()){
    Serial.println("SD Card initialization failed");
    disp.setBacklight(HIGH);
    disp.setCursor(0,0), disp.print("SD CARD FAIL");
    // while(1);
  }

  batfile = SD.open("Battery.txt", FILE_WRITE);
  if(batfile){
    Serial.println("SD Card file successfully opened");
    batfile.println("BATTERY TEST VOLTAGES AND CURRENT");
    batfile.println("TIMER\tBATTERY\tCURRENT\tBAT1\tBAT2\tBAT3\tBAT4\tBAT5\tBAT6\tBAT7\tBAT8\tBAT9\tBAT10");
  }else{
    Serial.println("SD Card file opening error");
  }
  batfile.close();

  pinMode(RelayCont, OUTPUT);
  digitalWrite(RelayCont, LOW);
  Serial.print("Clock\t"),Serial.print("Total\t"), Serial.print("BAT1\t"), Serial.print("BAT2\t"), Serial.print("BAT3\t"), Serial.print("BAT4\t"), Serial.print("BAT5\t"),
               Serial.print("BAT6\t"), Serial.print("BAT7\t"), Serial.print("BAT8\t"), Serial.print("BAT9\t"), Serial.println("BAT10\t");

  // Neopixel Strip
  strip.begin();           // INITIALIZE NeoPixel strip object (REQUIRED)
  strip.show();            // Turn OFF all pixels ASAP
  strip.setBrightness(50); // Set BRIGHTNESS to about 1/5 (max = 255)
}

// Main loop.
void loop() {

  // Evaluate Total Battery Pack Voltage
  BatteryVolt = 0;
  for (int k = 0; k < 10; k = k + 1) {
    BatteryVolt = BatteryVolt + tempCellVoltages[k];
  }

  /* Check and set charging state
      - Check for undervoltage condition (cells are discharged or low charge)
        - Enable charge relay
        - Disable load relay (unless loading state active) 
      - Check for overvoltage condition (cells are charged too high)
        - Disable charge relay
      - Check for "Negative-Delta-Voltage" (cells are charged too high and too quickly)
        - Disable charge relay
  */

  /* Check and set loading state
      - 


  */

  // Check for 1Hz datalog
  if(TimeToggle != oldTime){
    oldTime = TimeToggle;

    Serial.print(Timer),Serial.print("\t");
    
    // Print the values to the serial monitor. This will change to a SD card storage device.
    batfile = SD.open("Battery.txt", FILE_WRITE);
    Serial.print(BatteryVolt), Serial.print("\t");
    batfile.print(Timer), batfile.print("\t");
    batfile.print(BatteryVolt), batfile.print("\t");
    batfile.print("curr"), batfile.print("\t");
    for (int j = 0; j < 10; j = j + 1) {
      temp = tempCellVoltages[j];
      Serial.print(temp), Serial.print("\t");
      batfile.print(temp), batfile.print("\t");
    }
    Serial.println("");
    batfile.println("");
    batfile.close();
    
    // Print the Values to the LCD Display
    disp.setCursor(0,0), disp.print("B"), disp.setCursor(1,0),disp.print(BatteryVolt);
    disp.setCursor(7,0), disp.print("C"), disp.setCursor(8,0),disp.print("curr");
    disp.setCursor(13,0), disp.print("10:"), disp.setCursor(16,0), disp.print(tempCellVoltages[9]);
    disp.setCursor(0,1), disp.print("9:"), disp.setCursor(2,1), disp.print(tempCellVoltages[8]);
    disp.setCursor(7,1), disp.print("8:"), disp.setCursor(9,1), disp.print(tempCellVoltages[7]);
    disp.setCursor(14,1), disp.print("7:"), disp.setCursor(16,1), disp.print(tempCellVoltages[6]);
    disp.setCursor(0,2), disp.print("6:"), disp.setCursor(2,2), disp.print(tempCellVoltages[5]);
    disp.setCursor(7,2), disp.print("5:"), disp.setCursor(9,2), disp.print(tempCellVoltages[4]);
    disp.setCursor(14,2), disp.print("4:"), disp.setCursor(16,2), disp.print(tempCellVoltages[3]);
    disp.setCursor(0,3), disp.print("3:"), disp.setCursor(2,3), disp.print(tempCellVoltages[2]);
    disp.setCursor(7,3), disp.print("2:"), disp.setCursor(9,3), disp.print(tempCellVoltages[1]);
    disp.setCursor(14,3), disp.print("1:"), disp.setCursor(16,3), disp.print(tempCellVoltages[0]);

    SetLEDs();

    // Delay since it is not required to measure the cell voltages at very high rates. Play with this number to suit requirements.
    Timer = Timer+1;
  }

}// End main loop

// 1 Hz Timer to record the data to the SD card and the serial bus
ISR(TIMER4_COMPA_vect){
 TimeToggle++;
}

// Function to update the RGB LED indicators of cell voltage
void SetLEDs (){

  // Read the voltages at each analog input and store into a temporary array.
  for (int i = 0; i < 10; i = i + 1) {
    tempCellVoltages[i] = GetVoltage(CellVoltages[i], compensation[i]);
    if(tempCellVoltages[i] < 1.0){
      CellStat[i] = strip.Color(255,   0,   0); // Red
    }else if(tempCellVoltages[i] >= 1.0 && tempCellVoltages[i] < 1.2){
      CellStat[1] = strip.Color(200,   255,   0);; // Yellow
    }else if(tempCellVoltages[i] >= 1.2 && tempCellVoltages[i] < 1.6){
      CellStat[i] = strip.Color(0, 255,   0); // Green
    }else if(tempCellVoltages[i] >= 1.6){
      CellStat[i] = strip.Color(255, 0,   255); // Purple
    }
  }

  for(uint8_t i =0; i<strip.numPixels(); i++){
    strip.setPixelColor(i,CellStat[i]);
    delay(1);
  }
  strip.show();
  
}


// Function to read the analog input of the requested pin. It then converts this analog reading to a voltage.
float GetVoltage(int AnalogInput, float comp) {

  // Temporary variables for calculations and placeholders
  int tot = 0;
  int values[numReadings];
  for (int j = 0; j < numReadings; j = j + 1) {
    values[j] = 0;
  }
  int index = 0;
  float avg = 0;

  // Summing function. Takes the past "numReadings" amount of readings and sums them to be averaged.
  for (int i = 0; i < numReadings; i = i + 1) {
    tot = tot - values[index];
    values[index] = analogRead(AnalogInput);
    values[index] = values[index] / comp;
    tot = tot + values[index];
    index = index + 1;
    delay(1); // Delay for analog reading stability
  }

  // Average the total and calculate the voltage.
  avg = tot / numReadings;
  avg = avg * analogRef;
  avg = avg / 1023;

  return avg;
}

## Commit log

2021-07-20 Added KiCad Files and Test Code for Monitor
    [95947A018_ALUM FEM THRDED HEX STANDOFF.STEP, CUI_DEVICES_PJ-102AH.step, CUI_DEVICES_TB005-762-02BE.step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]
2022-11-08 Added files, need organisation
    [100SP1T1B4M2QE--3DModel-STEP-56544.STEP, 95947A018_ALUM FEM THRDED HEX STANDOFF.STEP, CUI_DEVICES_PJ-102AH.step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]
2022-11-08 Added README, modified file structure
    [100SP1T1B4M2QE--3DModel-STEP-56544.STEP, 95947A018_ALUM FEM THRDED HEX STANDOFF.STEP, CUI_DEVICES_PJ-102AH.step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]
2023-11-06 Added Code for battery testing unit
